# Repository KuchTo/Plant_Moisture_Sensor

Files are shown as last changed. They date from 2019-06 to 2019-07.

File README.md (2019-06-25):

# Plant_Moisture_Sensor
Monitors Plant earth Moisture and some Environment Paramanter like Temperature 

Kurzbeschreibung Projekt:

Mittels des hier vorgestellten Projektes wird der Wassergehalt der Erde überwacht. Dazu besitzt der Pflanzenwächter eine LED-Ampel, die bei feuchter Erde grün leuchtet und bei trockener Erde über gelb rot wird.

Hinweise:

Da die Feuchtigkeit der Erde über eine kapazitive Nahfeldmessung bestimmt wird, ist es notwendig, dass die Feuchtigkeit in unmittelbarer Nähe des Sensors gespeichert wird. Während i.d.R. normale (Blumen-)Pflanzenerde diese Bedingung erfüllt, ist dies bei u.a. bei Hydrokultursubstraten nicht gegeben !

Dieses Projekt ist daher für Hydrokulturpflanzen oder Luftwurzlerpflanzen (wie z.B. Orchideen) nicht geeignet! 

Da Pflanzen ganz unterschiedliche Anforderungen an Ihre Bewässerung habe, liegt die Interpretation der nötigen Aktionen auf die (Ampel-) Anzeige des Projektes ausschließlich in der Hand des Anwenders. 

Der Pflanzenwächter ist daher kein Ersatz für eine verantwortungsvolle- und pflanzengerechte Pflege der Pflanzen.

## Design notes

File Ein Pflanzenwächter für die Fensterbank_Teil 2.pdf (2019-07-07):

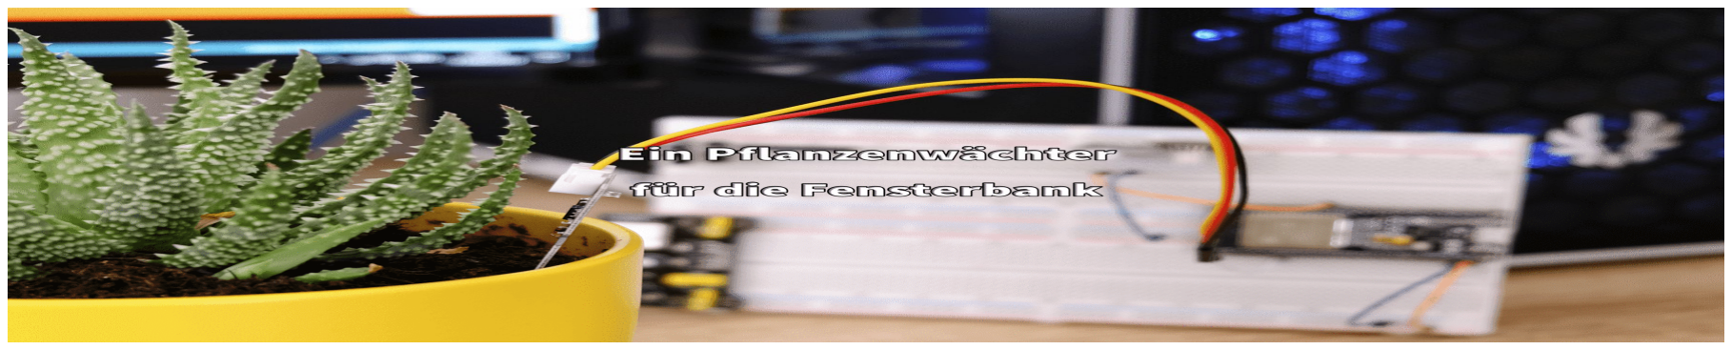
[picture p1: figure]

# Pflanzenwächter für die Fensterbank Teil 2 – Eine eigene Handy App

Hallo und willkommen zum zweiten Teil unserer Pflanzenwächterreihe. Obwohl unser Pflanzenwächter schon ganz gut funktioniert, finde ich es doch als Maker etwas umständlich immer mal wieder nach der Led - „Ampel“ zu schauen, um zu sehen, ob meine Pflanze gegossen werden muss. Viel praktischer fände ich es, wenn ich

jederzeit und überall einfach nur mal kurz auf das Handy schauen muss, um zu wissen,

## wie es der Pflanze zuhause geht. Daher werden wir uns in diesem Teil eine waschechte Handy APP für unseren Wächter bauen!

Doch bevor jetzt jemand jetzt denkt: Das geht doch nicht, das ist doch viel zu kompliziert, schauen wir uns doch mal zuvor genauer im App Store um. Es gibt nämlich eine bereits schon genau für unsere Zwecke konzipierte APP, die wir nur noch hier etwas anpassen müssen, da ein wenig Code zuzufügen müssen und dann das ganze

zusammenfügen! Danach funktioniert unsere APP genauso wie wir es wollen.

## Also los geht’s! Als ersten Schritt laden wir uns die App „Blynk“ aus dem App Store auf unser Handy. Die APP selbst ist kostenlos und kann für unseren, hier im zweiten Teil des Blogs, beschriebenen Anwendungsfall auch ohne weitere zusätzliche Kosten für

die App betrieben werden.

## Für einen späteren weiteren Ausbau der App innerhalb der Blogreihe reichen die „2000

Energie“ Einheiten der kostenlosen Variante jedoch unter Umständen nicht mehr aus.

## Es fallen aber unabhängig von der Ausbaustufe Kosten für die Datenübertragung vom Pflanzenwächter zum Handy an. Bitte berücksichtigt diese Kosten bei dem Nachbau des Projektes!

## Nachdem wir also die App Blynk aus dem Store heruntergeladen haben und diese zum ersten Mal starten, müssen wir uns zuerst einmal einen Account anlegen. Dazu tippen wir auf „Create New Account“

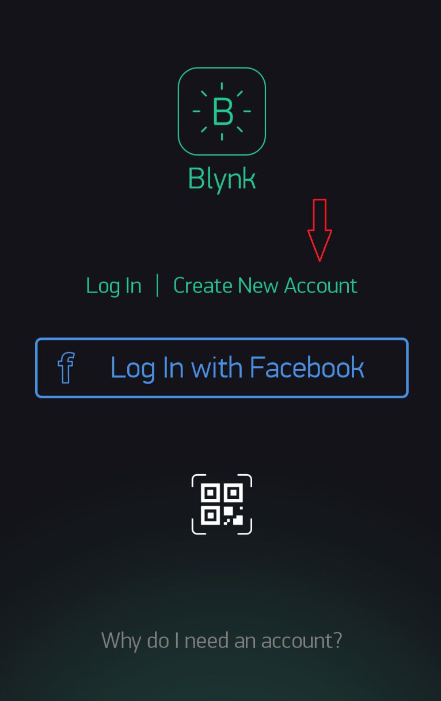
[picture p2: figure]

## Wir registrieren uns mit der eigenen E-Mail-Adresse und vergeben ein Passwort:

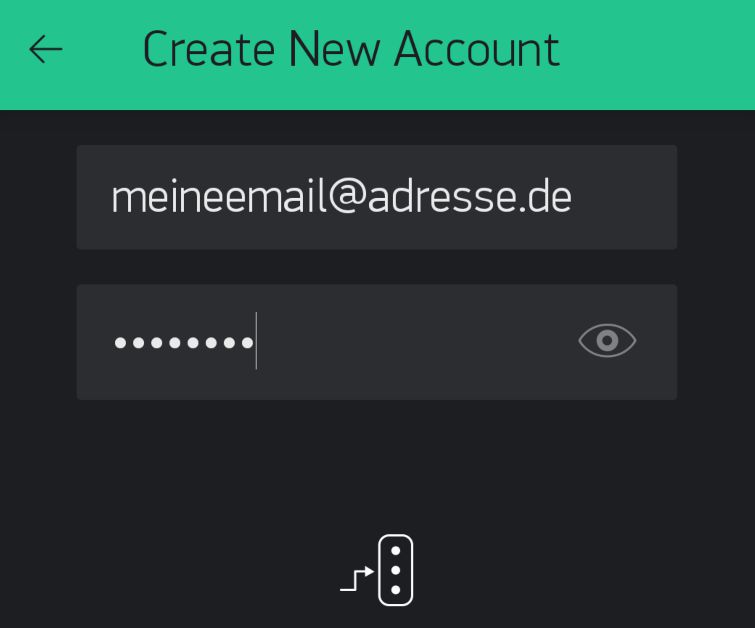
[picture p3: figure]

## Danach klicken wir auf neues Projekt:

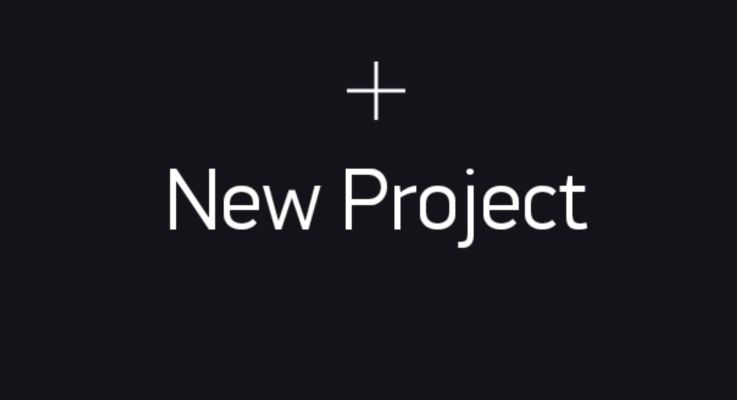
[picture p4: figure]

Wir landen in dem Dialog zur Anlage eines neuen Projektes. Hier müssen die Basisdaten des Projekts ein, wie z.B. den Projektnamen, unsere ESP32 Entwicklungsplattform und die gewünschte Verbindungsform. Es können verschiedene Verbindungsparameter mitgegeben werden, wie Z.B Bluetooth oder auch WLAN. Um jedoch auch Mobil unterwegs Daten empfangen zu können, muss der Verbindungstyp GSM gewählt werden. Nachfolgend sind die Einstellungen, die ich für mein Projekt gewählt habe, gezeigt:

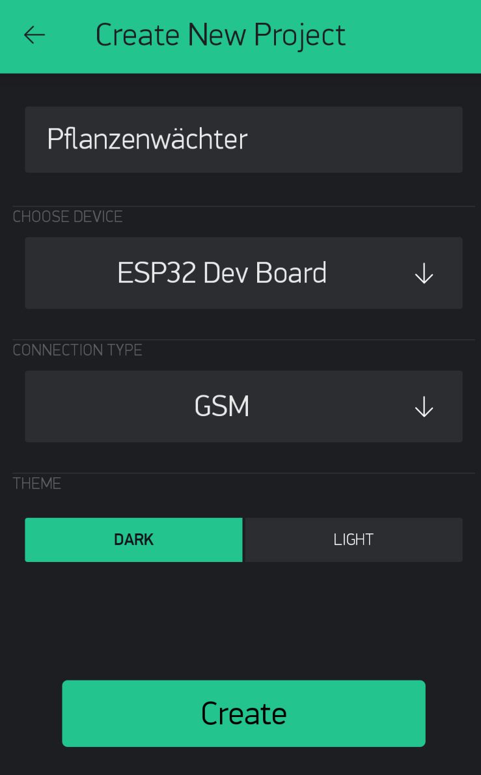
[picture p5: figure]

## Wir bestätigen die Angaben mit „Create“ und landen in einem leeren Projekt. Wir fügen unser erstes Aktives Element in unsere App über das „Plus“ Symbol in der Titelleiste hinzu:

## Wir wählen das Element „Gauge“ aus, und konfigurieren das Element. Zuerst vergeben wir einen NAMEN für das Element. Ich habe mich für den Namen

„Bodenfeuchte Pflanze 1“ entschieden.

## Danach wählen wir als Input Variable „V1“ aus, als Minimalwert 0 und als Maximalwert 100. Das Feld „LABEL“ ergänzen wir mit einem % und stellen als Reading Rate „Push“ ein. Bei dem Design können eine beliebige Farbe und eine beliebige Schriftgröße

gewählt werden.

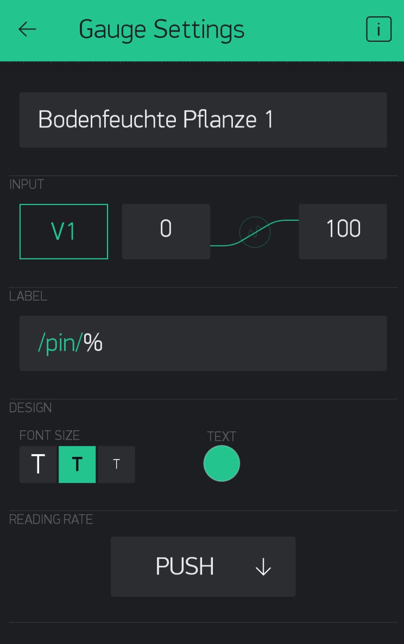
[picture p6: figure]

## Wir bestätigen die Einstellungen mit dem Pfeil links, und landen dann wieder in der Hauptansicht der APP:

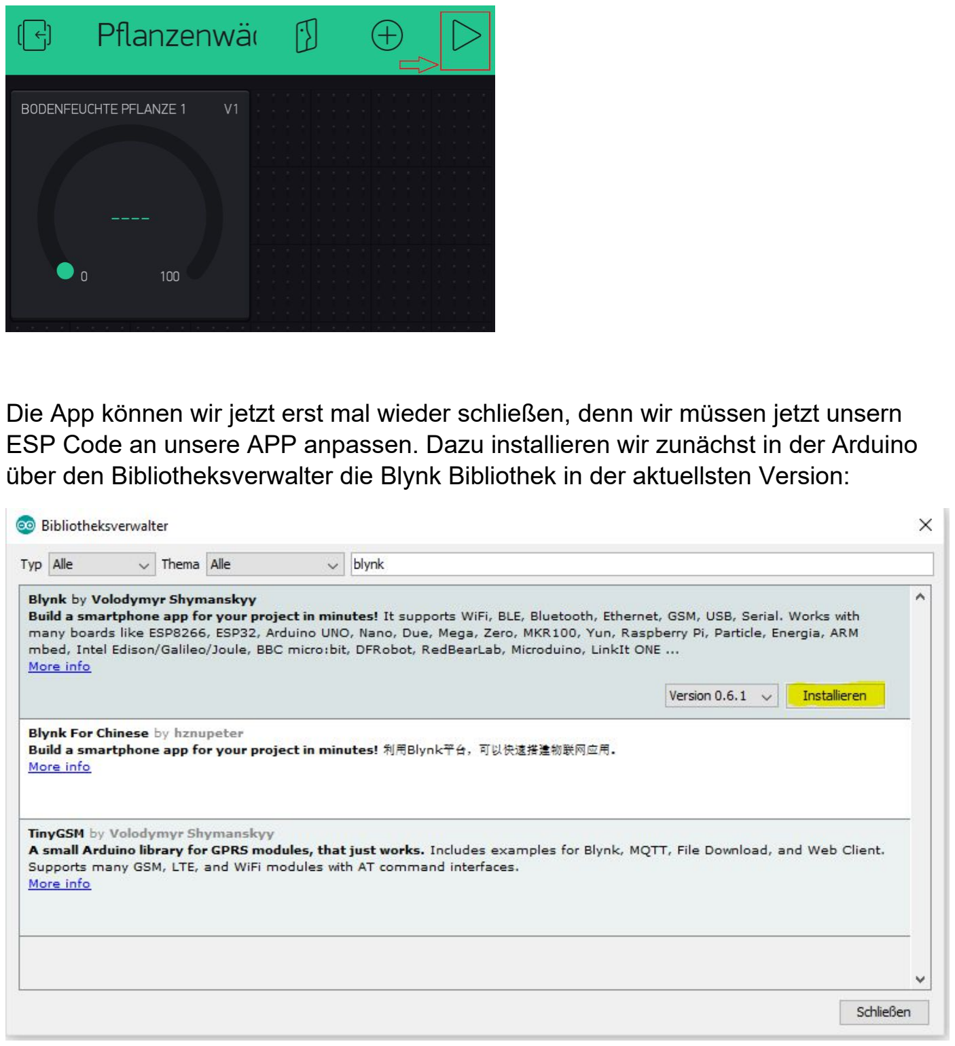
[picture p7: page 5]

## Die App können wir jetzt erst mal wieder schließen, denn wir müssen jetzt unsern ESP Code an unsere APP anpassen. Dazu installieren wir zunächst in der Arduino über den Bibliotheksverwalter die Blynk Bibliothek in der aktuellsten Version:

## Danach fügen wir folgenden Code in die IDE ein:

#include <driver/adc.h>

#include <WiFi.h>

#include <WiFiClient.h>

#include <BlynkSimpleEsp32.h>

// Portedefinierung Led's
#define LED_Rot 18 // Rote LED #define LED_Gelb 14 // Gelbe LED #define LED_Gruen 15 // Gruene LED

// LED PWM Einstellungen
#define PWMfreq 5000 // 5 Khz basisfrequenz #define PWMledChannelA 0

#define PWMledChannelB 1

#define PWMledChannelC 2

#define PWMresolution 8 // 8 Bit Resolution

#define ADCAttenuation ADC_ATTEN_DB_11 //ADC_ATTEN_DB_11 = 0-3,6V Dämpfung ADC

#define MoisureSens_Poll_Interval 60000 // Intervall zwischen zwei Bodenfeuchtemessungen in Millisekunden #define MaxSensors 1

#define BLYNK_PRINT Serial

#define BLYNK_NO_BUILTIN

#define BLYNK_NO_FLOAT

//#define BLYNK_DEBUG

struct MoistureSensorCalibrationData
{
int Data[MaxSensors*2] = {1650,2840}; // Calibration Data für Feuchtigkeitssensor. Bitte Projekt Text beachten und Werte ensprechend anpassen
};

struct MoistureSensorData
{
byte Percent[MaxSensors] = {0}; // Feuchtigkeitssensordaten in Prozent
byte Old_Percent[MaxSensors] = {0}; // Vorherige _ Feuchtigkeitssensordaten in Prozent (Zweck: DatenMenge einsparen.) };

//Global Variables
char auth[] = "xxxxxxxxxxxxxxxxxxxxxxxxxxxxxxxxxxxx"; // Hier lt. Anleitung Auth Token dere Blynk App eintragen (E-Mail).

// Deine WiFi Zugangsdaten.
char ssid[] = "WLANSSID";
char pass[] = "XXXXXXXX"; // Set Password to "" for open networks.

MoistureSensorCalibrationData MCalib;
MoistureSensorData MMeasure;
byte AttachedMoistureSensors; // Detected Active Moisture Sensors (Count)
unsigned long Moisure_ServiceCall_Handler = 0; // Delay Variable for Delay between Moisure Readings

void setup() {
pinMode(LED_Rot,OUTPUT);
pinMode(LED_Gelb,OUTPUT);
pinMode(LED_Gruen,OUTPUT);
Serial.begin(115200); // initialize serial communication at 115200 bits per second: ledcSetup(PWMledChannelA, PWMfreq, PWMresolution);
ledcSetup(PWMledChannelB, PWMfreq, PWMresolution);
ledcSetup(PWMledChannelC, PWMfreq, PWMresolution);
ledcAttachPin(LED_Rot, PWMledChannelA); // attach the channel to the GPIO to be controlled ledcAttachPin(LED_Gelb, PWMledChannelB);
ledcAttachPin(LED_Gruen, PWMledChannelC);
SetLedConfig(255,255,255);
Serial.println(F("Systemkonfiguration:")); AttachedMoistureSensors = DetectMoistureSensors(); Serial.print(AttachedMoistureSensors); Serial.println(F(" Bodenfeuchtigkeitsensor(en)")); Serial.print(F("Verbindung zu WLAN"));

delay(500);
Blynk.begin(auth, ssid, pass); // Initalize WiFi-Connection over Blync Library Serial.println(F(" erfolgreich."));
SetLedConfig(0,0,0);
Run_MoistureSensors(true);
}

byte DetectMoistureSensors () {
#define MinSensorValue 100 byte Detected = 0;

for (int i = 0;i < MaxSensors;i++)
{
int MSensorRawValue = ReadMoistureSensor_Raw_Val(i);
if ( MSensorRawValue > MinSensorValue) { Detected++; } else {break;} }
if (Detected < 1)
{
Serial.println(F("Keine Bodenfeuchtigkeitssesoren erkannt. System angehalten.")); esp_deep_sleep_start();
while(1) {}
}
return Detected;
}

bool SetLedConfig(byte Red,byte yellow,byte green) {
ledcWrite(PWMledChannelA, Red); // Rote LED ledcWrite(PWMledChannelB, yellow); // Gelbe LED ledcWrite(PWMledChannelC, green); // Gruene LED return true;
}

int ReadMoistureSensor_Raw_Val(byte Sensor)
{
int ReturnValue,i;
long sum = 0;
#define NUM_READS 6

adc1_config_width(ADC_WIDTH_BIT_12); //Range 0-4095 switch (Sensor)
{
case 0:
{
adc1_config_channel_atten(ADC1_CHANNEL_0,ADCAttenuation); for (i = 0; i < NUM_READS; i++){ // Averaging algorithm
sum += adc1_get_raw( ADC1_CHANNEL_0 ); //Read analog
}
ReturnValue = sum / NUM_READS;
break;
}
}

return ReturnValue;
}

bool Get_Moisture_DatainPercent()
{
bool ReadisValid = true;
for (int i = 0;i < AttachedMoistureSensors;i++)
{
if ((MCalib.Data[i] == 0) || (MCalib.Data[i+1] == 0)) // MinADC Value maxADC ADC Value {
ReadisValid = false;
return ReadisValid;
}
int RawMoistureValue= ReadMoistureSensor_Raw_Val(i); RawMoistureValue= MCalib.Data[i+1] - RawMoistureValue; RawMoistureValue=MCalib.Data[i] + RawMoistureValue; //Serial.println(MCalib.Data[i]);
//Serial.println(MCalib.Data[i+1]);
//Serial.println(RawMoistureValue);
MMeasure.Percent[i] = map(RawMoistureValue,MCalib.Data[i],MCalib.Data[i+1], 0, 100); if (MMeasure.Percent[i] > 100 ) { ReadisValid = false; }

}
return ReadisValid;
}

void Run_MoistureSensors (bool Init) // HauptFunktion zum Betrieb der Bodenfeuchtesensoren {
byte MinSensValue = 100;
if ((millis() - Moisure_ServiceCall_Handler >= MoisureSens_Poll_Interval) | (Init))
{
Moisure_ServiceCall_Handler = millis();
if (Get_Moisture_DatainPercent()) // Gültige aktuelle Daten Empfangen
{
for (int i = 0;i < AttachedMoistureSensors;i++)
{
if (MMeasure.Percent[i] != MMeasure.Old_Percent[i])
{
MMeasure.Old_Percent[i] = MMeasure.Percent[i];
if (MMeasure.Percent[i] < MinSensValue ) { MinSensValue = MMeasure.Percent[i]; }; Serial.print(F("Feuchtigkeitswert Sensor 1 in Prozent :")); Serial.print(MMeasure.Percent[0]);
Serial.println(F(" %"));
if (i == 0) {Blynk.virtualWrite(V1,MMeasure.Percent[i]); } // Aktualisiere Handywerte }
}
if (MMeasure.Percent[0] > 50)
{ SetLedConfig(0,0,20); }
else if (MMeasure.Percent[0] > 10) {
SetLedConfig(0,255,0);
}
else
{ SetLedConfig(255,0,0); }
}
else // Keine gültigen Daten empfangen
{
Serial.print(F("Bodenfeuchtigkeitssensor nicht kalibiert.Bitte kalibieren. RohDaten des Sensors 1:")); Serial.println(ReadMoistureSensor_Raw_Val(0));
SetLedConfig(255,255,255);
}
}
}

// Main Loop
void loop()
{
Run_MoistureSensors(false);
Blynk.run(); // Execute Blync Basic- Functions }

## Jetzt müssen wir noch unseren Code ein wenig anpassen. Zum einem muss im Code die WLAN Credentials (SSID und Passwort) an das heimische WLAN angepasst werden:

// Deine WiFi Zugangsdaten.
char ssid[] = "WLANSSID";
char pass[] = "XXXXXXXX"; // Set Password to "" for open networks.

## zum anderen haben wir bei der Anlage unseres Projektes in der AP ein Authenticator Token zugesendet bekommen:

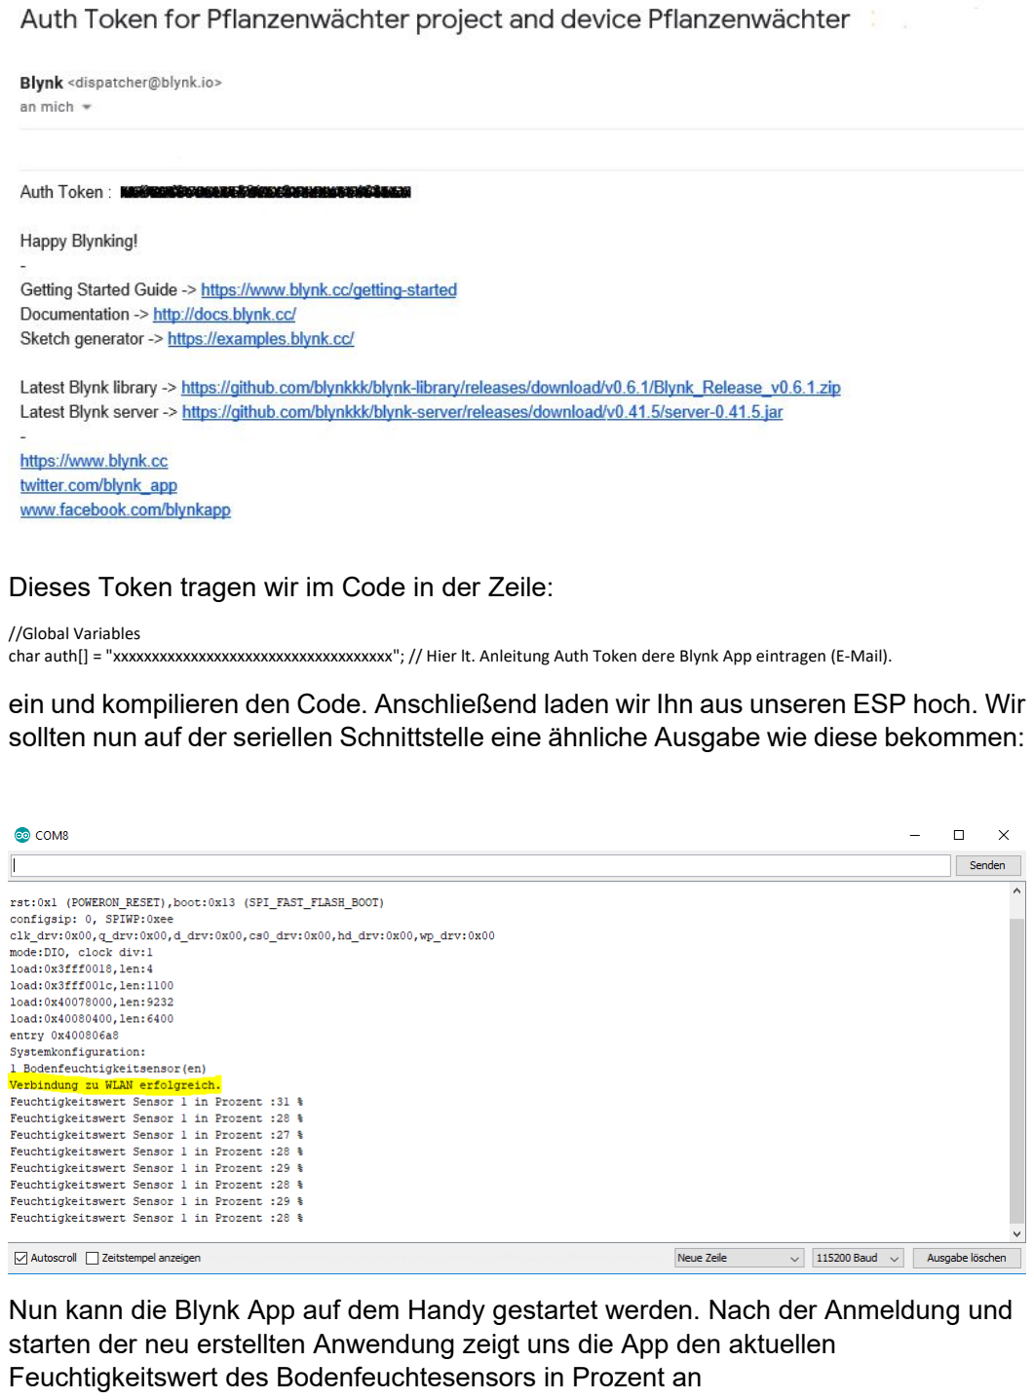
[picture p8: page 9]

## Dieses Token tragen wir im Code in der Zeile:

//Global Variables
char auth[] = "xxxxxxxxxxxxxxxxxxxxxxxxxxxxxxxxxxxx"; // Hier lt. Anleitung Auth Token dere Blynk App eintragen (E-Mail).

## ein und kompilieren den Code. Anschließend laden wir Ihn aus unseren ESP hoch. Wir sollten nun auf der seriellen Schnittstelle eine ähnliche Ausgabe wie diese bekommen:

## Nun kann die Blynk App auf dem Handy gestartet werden. Nach der Anmeldung und starten der neu erstellten Anwendung zeigt uns die App den aktuellen Feuchtigkeitswert des Bodenfeuchtesensors in Prozent an

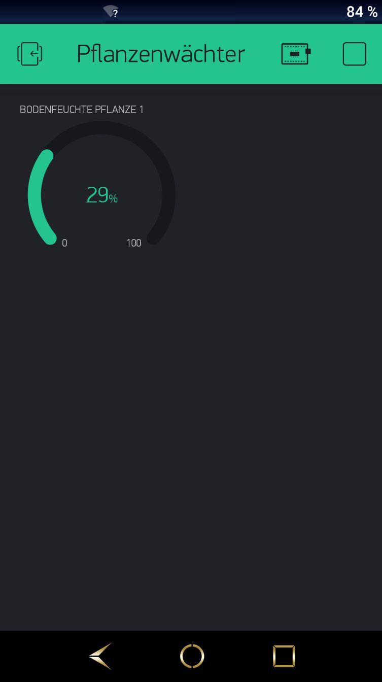
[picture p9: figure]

## Weitere Informationen über die Blynk APP und deren Verwendung in Controllern findest du unter

- Blynk Einführung -> https://www.blynk.cc/getting-started - Dokumentation -> http://docs.blynk.cc/ - Sketch Generator -> https://examples.blynk.cc/ - Aktuellste Blynk Bibliothek -> https://github.com/blynkkk/blynk-library/releases/download/v0.6.1/Blynk_Release_v0.6.1.zip - Aktuellster Blynk server -> https://github.com/blynkkk/blynk-server/releases/download/v0.41.5/server-0.41.5.jar - Blynk Startseite -> https://www.blynk.cc

Ich wünsche viel Spaß beim Nachbauen, und bis zum nächsten Mal.

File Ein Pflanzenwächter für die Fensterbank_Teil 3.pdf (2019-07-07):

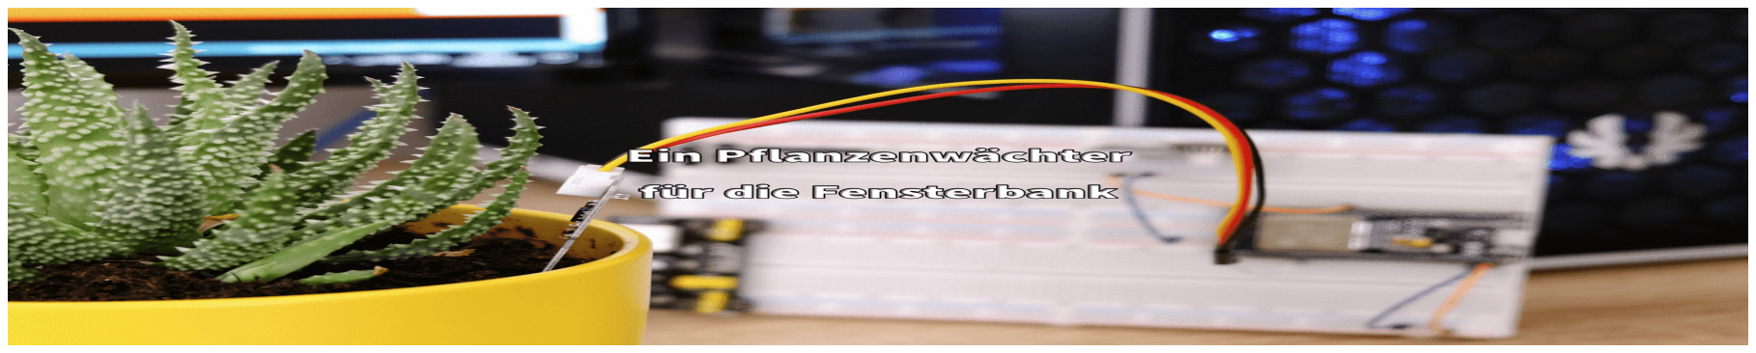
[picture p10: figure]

# Pflanzenwächter für die Fensterbank Teil 3 – Erweiterung der

Bodenfeuchtesensoren auf maximal sechs Stück.

In dem dritten Teil der Reihe „Pflanzenwächter“ kommen wir auf ein, in den vorherigen Teilen bereits implementiertes schaltungstechnisches Detail zurück und erweitern, die Anzahl der an unseren Pflanzenwächter anschließbaren Feuchtesensoren auf maximal sechs. Dem einen oder anderen sind vielleicht die bereits vorhandenen sechs Spannungsteiler aufgefallen, wobei bisher jedoch nur einer davon beschaltet war. Die restlichen 5 Spannungsteiler dienten bisher in der Hauptsache dazu, 5 von 6 Analog-

Digital Eingänge des ESP32 definiert auf 0 zu ziehen um sie einerseits an einem evtl.

unkontrolliertem Schwingen zu hindern, aber auch damit für unseren ESP feststellbar zu machen, an welchen der 6 Eingänge nun ein Feuchtesensor angeschlossen ist und an welchem nicht. Denn es soll, OHNE Änderung des Codes durch einfaches Anschließen eines weiteren Sensors (bis maximal 6) und einem anschließenden Resett des Systems möglich sein, weitere Sensoren nach Belieben und Notwendigkeit anzubinden. Wir können also eine beliebige Anzahl von mindestens 1 bis maximal 6 Sensoren, beginnend mit dem linken Port (GPIO36) folgend bis maximal zu dem rechten Port (GPIO 33) bestücken. Dabei dürfen jedoch keine Ports zwischen

Sensoren ausgelassen werden, da diese andernfalls nicht erkannt werden.

## Nachfolgend ist die Maximalbestückung mit Feuchtesensoren gezeigt:

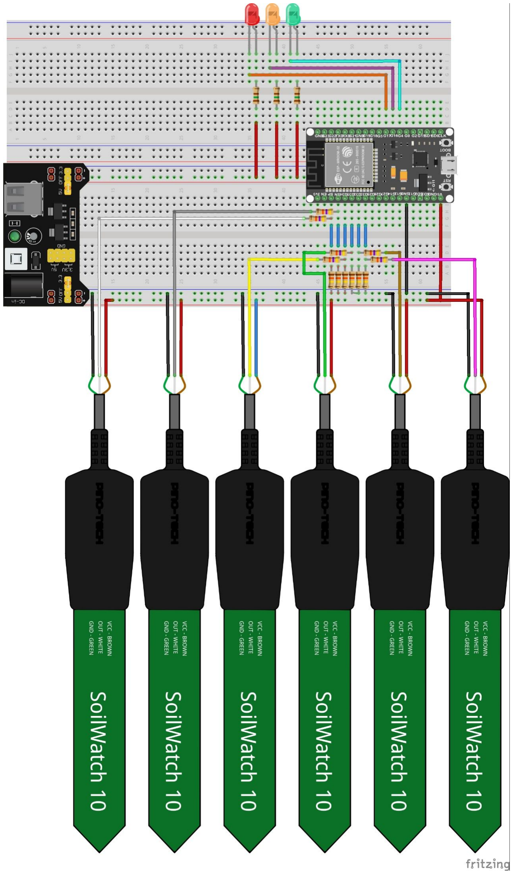
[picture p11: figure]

## Unsere Teileliste erweitert sich somit auf:

## - 1 x LED Farbe Grün (560nm); 5 mm - 1x LED Farbe Gelb (605nm); 5 mm - 1x LED Farbe Rot (633nm); 5 mm

- 6x130kΩ Wiederstand Toleranz ±1%;

## - 6x 47kΩ Wiederstand Toleranz ±1

- 3x 150Ω Wiederstand Toleranz ±1%;

## - 6x Kapazitiver Feuchtesensor

- 1x ESP32-38Pin Variante Generic; Typ NodeMCU-32S; Beinchen 38;

## - 1x YwRobot Breadboard Spannungsversorgung

## Nachdem wir nun die nötigen Hardwareänderungen durchgeführt haben, müssen wir noch unseren Code auf dem ESP ein wenig anpassen sowie unsere Handy-APP erweitern. Zuerst laden wir folgenden Code auf unseren ESP hoch:

#include <driver/adc.h>

#include <WiFi.h>

#include <WiFiClient.h>

#include <BlynkSimpleEsp32.h>

// Portedefinierung Led's
#define LED_Rot 18 // Rote LED #define LED_Gelb 14 // Gelbe LED

#define LED_Gruen 15 // Gruene LED

// LED PWM Einstellungen
#define PWMfreq 5000 // 5 Khz basisfrequenz für LED Anzeige #define PWMledChannelA 0

#define PWMledChannelB 1

#define PWMledChannelC 2

#define PWMresolution 8 // 8 Bit Resolution für LED PWM

//Sonstige Definitionen
#define ADCAttenuation ADC_ATTEN_DB_11 //ADC_ATTEN_DB_11 = 0-3,6V Dämpfung ADC (ADC Erweiterung #define MoisureSens_Poll_Interval 300000 // Intervall zwischen zwei Bodenfeuchtemessungen in Millisekunden -> alle 5 Minuten Datenpaket an Handy senden

#define MaxSensors 6 | // Maximale Anzahl an anschließbaren FeuchteSensoren

#define StartInit true

#define Sens_Calib true

#define Sens_NOTCalib false

// Blynk APP Definitionen
#define BLYNK_GREEN | "#23C48E"

#define BLYNK_BLUE | "#04C0F8"

#define BLYNK_YELLOW "#ED9D00"

#define BLYNK_RED | "#D3435C"

#define BLYNK_BLACK | "#000000"

#define BLYNK_PRINT Serial #define BLYNK_NO_BUILTIN

#define BLYNK_NO_FLOAT

//#define BLYNK_DEBUG

struct MoistureSensorCalibrationData
{
int Data[MaxSensors*2] = {0,0,0,0,0,0,0,0,0,0,0,0,}; // Calibration Data für Feuchtigkeitssensor. Bitte Projekt Text beachten und Werte ensprechend anpassen
String SensorName[MaxSensors] = {"Pflanze 1","Pflanze 2","Pflanze 3","Pflanze 4","Pflanze 5","Pflanze 6"}; // Sensorname, der auch in der APP als Überschrift angezeigt wird
byte StatusBorderPercentValues[MaxSensors*2][2]= { {10,50}, // Zweidimensinonales Array für Prozentgrenzwerte (Ampel) jeweils Einzeln pro Feuchtesensor (1 -6)
{10,50},
{10,50},

{10,50},
{10,50},
{10,50}};
};

struct MoistureSensorData
{
int Percent[MaxSensors] = {0,0,0,0,0,0}; // Feuchtigkeitssensordaten in Prozent
byte Old_Percent[MaxSensors] = {0,0,0,0,0,0}; // Vorherige _ Feuchtigkeitssensordaten in Prozent (Zweck: DatenMenge einsparen.)
bool DataValid [MaxSensors] = {false,false,false,false,false,false};
};

//Global Variables

char auth[] = "xxxxxxxxxxxxxxxxxxxxxxxxxxxxxxxx"; // Hier lt. Anleitung Auth Token dere Blynk App eintragen (E-Mail). // Deine WiFi Zugangsdaten.
char ssid[] = "Deine_WLAN_SSID"; | // Bitte an eigene WLAN SSID anpassen
char pass[] = "Dein _WLAN _Passwort!"; | // Bitte an eigene WLAN Passwort anpassen

MoistureSensorCalibrationData MCalib;
MoistureSensorData MMeasure;
byte AttachedMoistureSensors; // Detected Active Moisture Sensors (Count)
unsigned long Moisure_ServiceCall_Handler = 0; // Delay Variable for Delay between Moisure Readings

void setup() {
pinMode(LED_Rot,OUTPUT);
pinMode(LED_Gelb,OUTPUT);
pinMode(LED_Gruen,OUTPUT);
Serial.begin(115200); // initialize serial communication at 115200 bits per second: ledcSetup(PWMledChannelA, PWMfreq, PWMresolution);
ledcSetup(PWMledChannelB, PWMfreq, PWMresolution);
ledcSetup(PWMledChannelC, PWMfreq, PWMresolution);
ledcAttachPin(LED_Rot, PWMledChannelA); // attach the channel to the GPIO to be controlled ledcAttachPin(LED_Gelb, PWMledChannelB);
ledcAttachPin(LED_Gruen, PWMledChannelC);
SetLedConfig(255,255,255);
Serial.println(F("Systemkonfiguration:")); AttachedMoistureSensors = DetectMoistureSensors(); Serial.print(AttachedMoistureSensors); Serial.println(F(" Bodenfeuchtigkeitsensor(en)"));
Serial.print(F("Verbindung zu WLAN"));
delay(500);
Blynk.begin(auth, ssid, pass); // Initalize WiFi-Connection over Blync Library Serial.println(F(" erfolgreich."));
SetLedConfig(0,0,0);
Init_Blynk_APP();
Run_MoistureSensors(StartInit);
for (int i = AttachedMoistureSensors;i < 6;i++) { Update_Blynk_APP(i,Sens_Calib); }; }

byte DetectMoistureSensors ()
{
#define MinSensorValue 100 byte Detected = 0;

for (int i = 0;i < MaxSensors;i++)
{
int MSensorRawValue = ReadMoistureSensor_Raw_Val(i);
if ( MSensorRawValue > MinSensorValue) { Detected++; } else {break;} }
if (Detected < 1)
{
Serial.println(F("Keine Bodenfeuchtigkeitssesoren erkannt. System angehalten.")); esp_deep_sleep_start();
while(1) {}
}
return Detected;
}

bool SetLedConfig(byte Red,byte yellow,byte green) {
ledcWrite(PWMledChannelA, Red); // Rote LED ledcWrite(PWMledChannelB, yellow); // Gelbe LED ledcWrite(PWMledChannelC, green); // Gruene LED return true;
}

int ReadMoistureSensor_Raw_Val(byte Sensor) {
int ReturnValue,i;
long sum = 0;
#define NUM_READS 6

adc1_config_width(ADC_WIDTH_BIT_12); //Range 0-4095 switch (Sensor)
{
case 0:
{
adc1_config_channel_atten(ADC1_CHANNEL_0,ADCAttenuation); for (i = 0; i < NUM_READS; i++){ // Averaging algorithm
sum += adc1_get_raw( ADC1_CHANNEL_0 ); //Read analog
}
ReturnValue = sum / NUM_READS;
break;
}
case 1:
{
adc1_config_channel_atten(ADC1_CHANNEL_3,ADCAttenuation); for (i = 0; i < NUM_READS; i++){ // Averaging algorithm
sum += adc1_get_raw( ADC1_CHANNEL_3 ); //Read analog
}
ReturnValue = sum / NUM_READS;
break;
}
case 2:
{
adc1_config_channel_atten(ADC1_CHANNEL_6,ADCAttenuation); for (i = 0; i < NUM_READS; i++){ // Averaging algorithm
sum += adc1_get_raw( ADC1_CHANNEL_6 ); //Read analog
}
ReturnValue = sum / NUM_READS;
break;
}
case 3:
{
adc1_config_channel_atten(ADC1_CHANNEL_7,ADCAttenuation); for (i = 0; i < NUM_READS; i++){ // Averaging algorithm
sum += adc1_get_raw( ADC1_CHANNEL_7 ); //Read analog
}
ReturnValue = sum / NUM_READS;
break;
}
case 4:
{
adc1_config_channel_atten(ADC1_CHANNEL_4,ADCAttenuation); for (i = 0; i < NUM_READS; i++){ // Averaging algorithm
sum += adc1_get_raw( ADC1_CHANNEL_4 ); //Read analog
}
ReturnValue = sum / NUM_READS;
break;
}
default:
{
adc1_config_channel_atten(ADC1_CHANNEL_5,ADCAttenuation); for (i = 0; i < NUM_READS; i++){ // Averaging algorithm
sum += adc1_get_raw( ADC1_CHANNEL_5 ); //Read analog
}
ReturnValue = sum / NUM_READS;
break;
}
}

return ReturnValue;
}

void Init_Blynk_APP()
{
Blynk.setProperty(V1,"label",MCalib.SensorName[0]); Blynk.setProperty(V2,"label",MCalib.SensorName[1]); Blynk.setProperty(V3,"label",MCalib.SensorName[2]); Blynk.setProperty(V4,"label",MCalib.SensorName[3]); Blynk.setProperty(V5,"label",MCalib.SensorName[4]); Blynk.setProperty(V6,"label",MCalib.SensorName[5]); }

void Update_Local_Display() {
byte red1 = 0;
byte yellow1 = 0;
byte green1 = 0;
for (byte i = 0;i < AttachedMoistureSensors;i++) {
if (MMeasure.DataValid[i])
{
if ( MMeasure.Percent[i] > MCalib.StatusBorderPercentValues[i][1])
{
green1++;
} else if ( MMeasure.Percent[i] > MCalib.StatusBorderPercentValues[i][0]) {
yellow1++;
} else
{
red1++;
}
}
}
if (red1 > 0)
{ SetLedConfig(255,0,0); } else if (yellow1 > 0)
{ SetLedConfig(0,255,0); } else if (green1 > 0)
{ SetLedConfig(0,0,100); } else
{ SetLedConfig(100,100,100); }
}

void Update_Blynk_APP(byte Sensor,bool Calibrated) {
switch (Sensor)
{
case 0:
{
if ((MMeasure.DataValid[0]) & (Calibrated))
{
if ( MMeasure.Percent[0] > MCalib.StatusBorderPercentValues[0][1])
{
Blynk.setProperty(V1,"color",BLYNK_GREEN);
} else if ( MMeasure.Percent[0] > MCalib.StatusBorderPercentValues[0][0]) {
Blynk.setProperty(V1,"color",BLYNK_YELLOW);
} else
{
Blynk.setProperty(V1,"color",BLYNK_RED);
}
delay(100);
Blynk.virtualWrite(V1,MMeasure.Percent[0]); } else
{
if (Calibrated)
{
Blynk.setProperty(V1,"label","Deaktiviert"); delay(100);
Blynk.virtualWrite(V1,0);
delay(100);
Blynk.setProperty(V1,"color",BLYNK_BLACK); }
else
{
Blynk.virtualWrite(V1,0);
delay(100);
Blynk.setProperty(V1,"color",BLYNK_BLUE); }
}
break;
}
case 1:
{
if ((MMeasure.DataValid[1]) & (Calibrated))
{
if ( MMeasure.Percent[1] > MCalib.StatusBorderPercentValues[1][1]) {

Blynk.setProperty(V2,"color",BLYNK_GREEN);
} else if ( MMeasure.Percent[1] > MCalib.StatusBorderPercentValues[1][0]) {
Blynk.setProperty(V2,"color",BLYNK_YELLOW);
} else
{
Blynk.setProperty(V2,"color",BLYNK_RED);
}
delay(100);
Blynk.virtualWrite(V2,MMeasure.Percent[1]); } else
{
if (Calibrated)
{
Blynk.setProperty(V2,"label","Deaktiviert"); delay(100);
Blynk.virtualWrite(V2,0);
delay(100);
Blynk.setProperty(V2,"color",BLYNK_BLACK); }
else
{
Blynk.virtualWrite(V2,0);
delay(100);
Blynk.setProperty(V3,"color",BLYNK_BLUE); }
}
break;
}
case 2:
{
if ((MMeasure.DataValid[2]) & (Calibrated))
{
if ( MMeasure.Percent[2] > MCalib.StatusBorderPercentValues[2][1])
{
Blynk.setProperty(V3,"color",BLYNK_GREEN);
} else if ( MMeasure.Percent[2] > MCalib.StatusBorderPercentValues[2][0]) {
Blynk.setProperty(V3,"color",BLYNK_YELLOW);
} else
{
Blynk.setProperty(V3,"color",BLYNK_RED);
}
delay(100);
Blynk.virtualWrite(V3,MMeasure.Percent[2]); } else
{
if (Calibrated)
{
Blynk.setProperty(V3,"label","Deaktiviert"); delay(100);
Blynk.virtualWrite(V3,0);
delay(100);
Blynk.setProperty(V3,"color",BLYNK_BLACK); }
else
{
Blynk.virtualWrite(V3,0);
delay(100);
Blynk.setProperty(V3,"color",BLYNK_BLUE); }
}
break;
}
case 3:
{
if ((MMeasure.DataValid[3]) & (Calibrated))
{
if ( MMeasure.Percent[3] > MCalib.StatusBorderPercentValues[3][1])
{
Blynk.setProperty(V4,"color",BLYNK_GREEN);
} else if ( MMeasure.Percent[3] > MCalib.StatusBorderPercentValues[3][0]) {
Blynk.setProperty(V4,"color",BLYNK_YELLOW);
} else
{
Blynk.setProperty(V4,"color",BLYNK_RED);

}
delay(100);
Blynk.virtualWrite(V4,MMeasure.Percent[3]); } else
{
if (Calibrated)
{
Blynk.setProperty(V4,"label","Deaktiviert"); delay(100);
Blynk.virtualWrite(V4,0);
delay(100);
Blynk.setProperty(V4,"color",BLYNK_BLACK); }
else
{
Blynk.virtualWrite(V4,0);
delay(100);
Blynk.setProperty(V4,"color",BLYNK_BLUE); }
}
break;
}
case 4:
{
if ((MMeasure.DataValid[4]) & (Calibrated))
{
if ( MMeasure.Percent[4] > MCalib.StatusBorderPercentValues[4][1])
{
Blynk.setProperty(V5,"color",BLYNK_GREEN);
} else if ( MMeasure.Percent[4] > MCalib.StatusBorderPercentValues[4][0]) {
Blynk.setProperty(V5,"color",BLYNK_YELLOW);
} else
{
Blynk.setProperty(V5,"color",BLYNK_RED);
}
delay(100);
Blynk.virtualWrite(V5,MMeasure.Percent[4]); } else
{
if (Calibrated)
{
Blynk.setProperty(V5,"label","Deaktiviert"); delay(100);
Blynk.virtualWrite(V5,0);
delay(100);
Blynk.setProperty(V5,"color",BLYNK_BLACK); }
else
{
Blynk.virtualWrite(V5,0);
delay(100);
Blynk.setProperty(V5,"color",BLYNK_BLUE); }
}
break;
}
default:
{
if ((MMeasure.DataValid[5]) & (Calibrated))
{
if ( MMeasure.Percent[5] > MCalib.StatusBorderPercentValues[5][1])
{
Blynk.setProperty(V6,"color",BLYNK_GREEN);
} else if ( MMeasure.Percent[5] > MCalib.StatusBorderPercentValues[5][0]) {
Blynk.setProperty(V6,"color",BLYNK_YELLOW);
} else
{
Blynk.setProperty(V6,"color",BLYNK_RED);
}
delay(100);
Blynk.virtualWrite(V6,MMeasure.Percent[5]); } else
{
if (Calibrated)
{

Blynk.setProperty(V6,"label","Deaktiviert"); delay(100);
Blynk.virtualWrite(V6,0);
delay(100);
Blynk.setProperty(V6,"color",BLYNK_BLACK); }
else
{
Blynk.virtualWrite(V6,0);
delay(100);
Blynk.setProperty(V6,"color",BLYNK_BLUE); }
}
break;
}
} // End Switch
}

void Get_Moisture_DatainPercent()
{
byte CalibDataOffset = 0;
for (byte i = 0;i < AttachedMoistureSensors;i++)
{
CalibDataOffset = i *2;
int RawMoistureValue = ReadMoistureSensor_Raw_Val(i);
if ((MCalib.Data[CalibDataOffset] == 0) || (MCalib.Data[CalibDataOffset+1] == 0)) // MinADC Value maxADC ADC Value {
MMeasure.Percent[i] = RawMoistureValue;
MMeasure.DataValid[i] = false;
} else
{
RawMoistureValue= MCalib.Data[CalibDataOffset+1] - RawMoistureValue; RawMoistureValue=MCalib.Data[CalibDataOffset] + RawMoistureValue;
MMeasure.Percent[i] = map(RawMoistureValue,MCalib.Data[CalibDataOffset],MCalib.Data[CalibDataOffset+1], 0, 100);
if ((MMeasure.Percent[i] > 100 ) | (MMeasure.Percent[i] < 0 ))
{
MMeasure.Percent[i] = RawMoistureValue;
MMeasure.DataValid[i] = false;
} else { MMeasure.DataValid[i] = true; } }
}
return ;
}

void Run_MoistureSensors (bool Init) // HauptFunktion zum Betrieb der Bodenfeuchtesensoren {
byte MinSensValue = 100;
if ((millis() - Moisure_ServiceCall_Handler >= MoisureSens_Poll_Interval) | (Init))
{
Moisure_ServiceCall_Handler = millis();
Get_Moisture_DatainPercent();
for (int i = 0;i < AttachedMoistureSensors;i++) {
if (MMeasure.DataValid[i])
{

if (MMeasure.Percent[i] != MMeasure.Old_Percent[i])
{

MMeasure.Old_Percent[i] = MMeasure.Percent[i];
if (MMeasure.Percent[i] < MinSensValue ) { MinSensValue = MMeasure.Percent[i]; }; Serial.print(F("Feuchtigkeitswert Sensor "));
Serial.print(i);
Serial.print(F(" in Prozent :"));
Serial.print(MMeasure.Percent[i]);
Serial.println(F(" %"));
Update_Blynk_APP(i,Sens_Calib); // Aktualisiere Handywerte }
} else
{
Update_Blynk_APP(i,Sens_NOTCalib); // Aktualisiere Handywerte Serial.print(F("Sensor "));
Serial.print(i);
Serial.print(F(" nicht kalibiert. Bitte kalibrieren. Rohdatenwert:")); Serial.println(MMeasure.Percent[i]);

}
}
Update_Local_Display(); // Aktualisiere lokales Pflanzenwächter Display (Led) }
}

// Main Loop
void loop()
{
Run_MoistureSensors(false);
Blynk.run(); // Execute Blync Basic- Functions }

## Es ist vor dem hochladen auf unseren ESP zu beachten, das folgende Parameter/Codezeilen an die jeweiligen Bedürfnisse angepasst werden müssen:

int Data[MaxSensors*2] = {0,0,0,0,0,0,0,0,0,0,0,0,};

Werte bitte gemäß Beschreibung in Teil 1 der Reihe anpassen.

## #define MoisureSens_Poll_Interval 300000

## Intervall zwischen zwei Bodenfeuchtemessungen in Millisekunden. Der Wert hat darauf Einfluss, wie oft die Handydaten aktualisiert werden, und damit auch, welches Datenvolumen für die Übertragung pro Zeit anfällt. Je höher, desto größeres

Intervall. Bitte auf einen Wert setzen, der zu dem eigenen Datenvolumen bzw.

## Budget passt. [Beispiel: 300000 ms = 5 Minuten Datenübertragungsintervall}

char auth[] = "xxxxxxxxxxxxxxxxxxxxxxxxxxxxxxxx";
char ssid[] = "Deine_WLAN_SSID";
char pass[] = "Dein _WLAN _Passwort!";

Werte bitte gemäß Beschreibung in Teil 2 der Reihe anpassen.

## Es können folgende Parameter/Codezeilen, an die jeweiligen Bedürfnisse angepasst werden:

String SensorName[MaxSensors] = {"Pflanze 1","Pflanze 2","Pflanze 3","Pflanze 4","Pflanze 5","Pflanze 6"};

Feuchtesensorname, der in der APP als Überschrift angezeigt wird.

byte StatusBorderPercentValues[MaxSensors*2][2]= { {10,50}, …..

Zweidimensionales Array für Prozentgrenzwerte (Ampel) jeweils einzeln pro Feuchtesensor (1 -6). Hat Einfluss auf die „Ampel“ Anzeige und die Anzeige der Werte in der APP. Erster Wer (10) gibt die Übergangsgrenze zwischen Status „rot“ und Status „gelb“ an. Zweiter Wert gibt die Übergangsgrenze zwischen Status „gelb“ und Status „grün“ an. Beispiel: ab 51 % Bodenfeuchte „grün“ ab 9% Bodenfeuchte „rot“

## Wenn alle genannten Parameter korrekt definiert worden sollte die Ausgabe auf dem seriellen Monitor nun wie folgt aussehen:

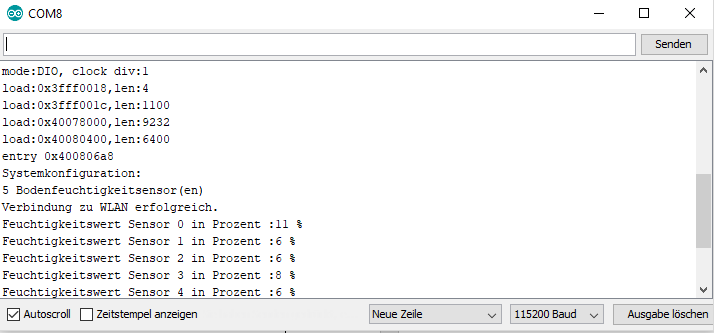
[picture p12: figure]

Hinweis: In diesem Beispiel sind statt max6. nur 5 Sensoren angeschlossen

## Als nächstes müssen wir unsere HandyApp noch auf die veränderte Hardware und

Firmware anpassen.

## Da wir in unserer Blynk HandyAPP nur 2000 Energiepunkte kostenlos zur Verfügung gestellt bekommen, müssen wir bei 6 angebundenen Sensoren etwas haushalten. Im

ersten Schritt löschen wir daher das im zweiten Teil angelegte „Gauge“ Element.

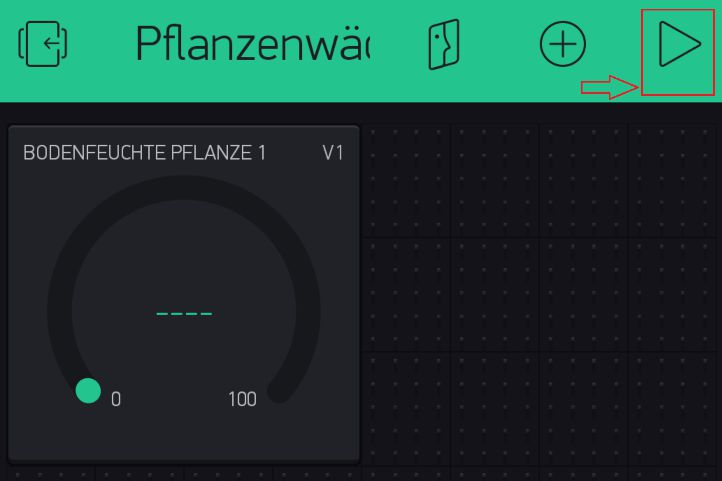
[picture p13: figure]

## Das „Gauge“ Element ersetzen wir durch das “Level H“ Element

## Nun fügen wir also zur Anzeige der aktuellen Bodenfeuchte das Energiegünstigere

Element „Level H“ insgesamt 6-mal hinzu.

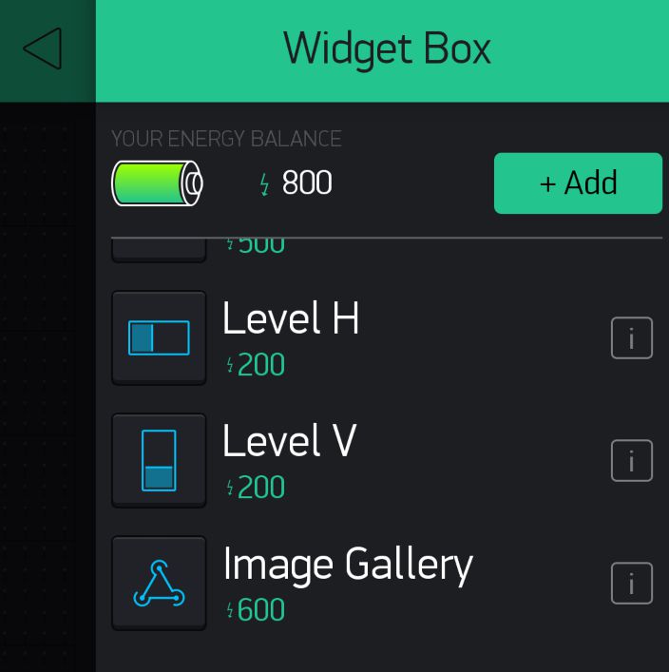
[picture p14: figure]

## Nun sollte unsere Oberfläche ungefähr so aussehen:

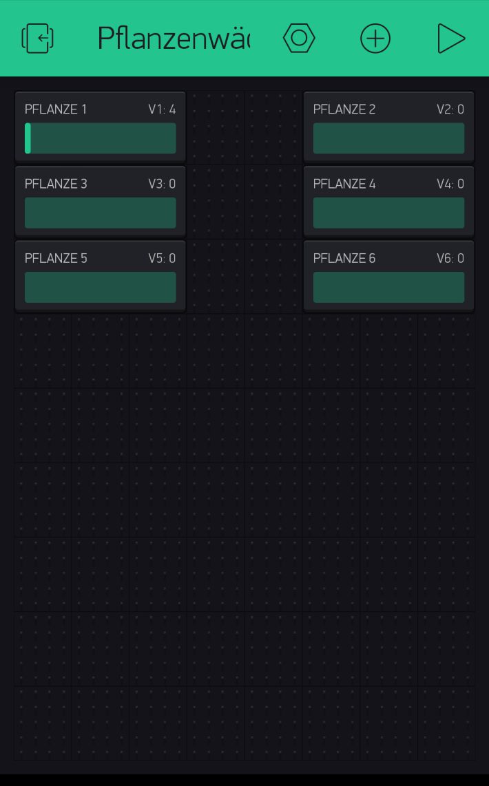
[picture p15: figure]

## Nun müssen wir noch drei Werte jeweilig in den Eigenschaften der 6 Elemente anpassen. Exemplarisch zeige ich hier die Einstellungen für den ersten Sensor

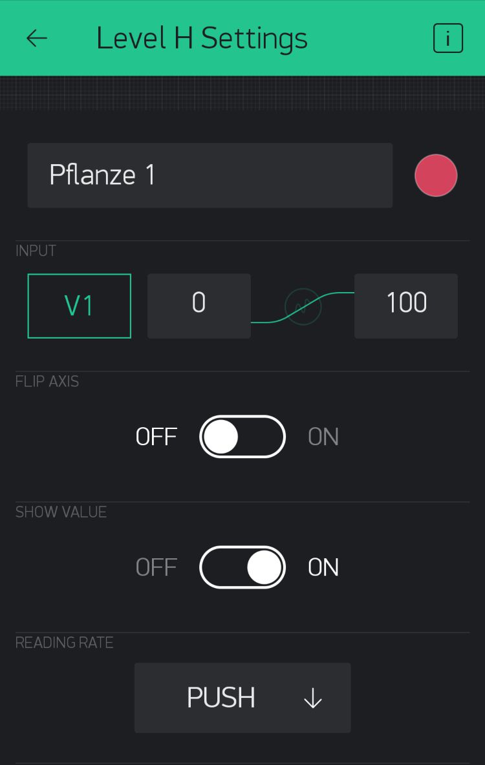
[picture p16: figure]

Die wichtigste Anpassung ist hierbei die Input Variable. Diese muss fortlaufend für jedes „Level H“ Element angefangen von Input „V1“ für Pflanze 1 bis zu „V6“ für Pflanze 6 definiert werden. „V“ steht dabei für „Virtuelle Pins“ und ermöglichen eine Zuordnung zwischen den Elementen der APP und der Anweisungen im Code. Weiterhin wählen wir als Minimalwert 0 und als Maximalwert 100 aus. Als drittes definieren wir als Reading Rate „Push“ ein. Bei dem Design können eine beliebige Farbe, eine beliebige Schriftgröße und ein beliebiger Name gewählt werden, da diese Parameter später

durch unser Programm auf dem ESP gesetzt bzw. definiert werden.

## Das Endergebnis, bei Aktivierung des Projekts sollte nun ungefähr wie folgt aussehen:

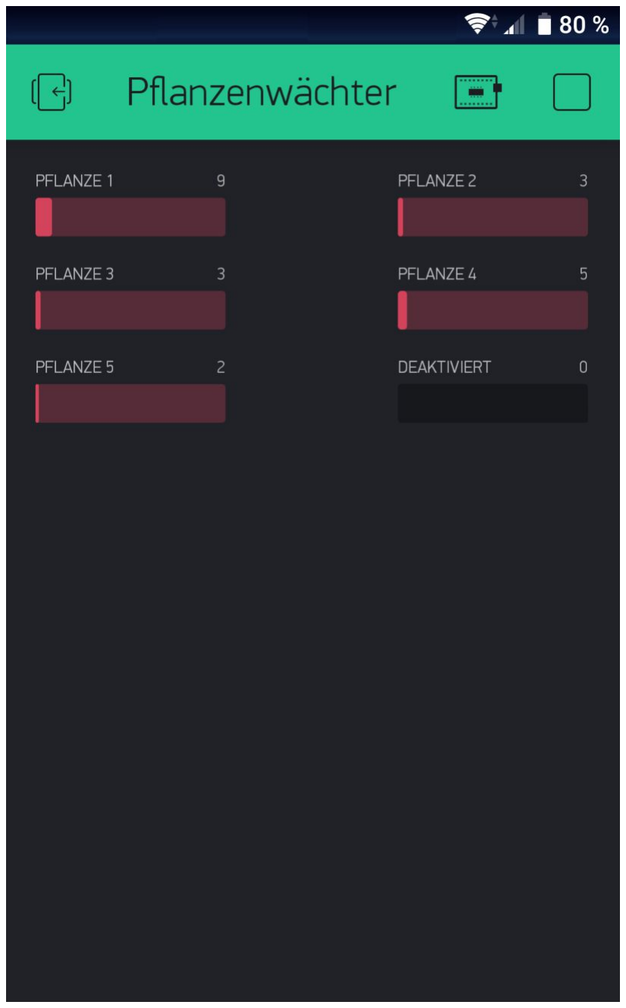
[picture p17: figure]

(der letzte Sensor wird als deaktiviert dargestellt, da ich in dem Beispiel nur 5 Sensoren angeschlossen habe. Bei Verwendung von 6 Sensoren wird das Feld automatisch aktiviert)

## Weitere Informationen über die Blynk APP und deren Verwendung in Controllern findest du unter

- Blynk Einführung -> https://www.blynk.cc/getting-started - Dokumentation -> http://docs.blynk.cc/ - Sketch Generator -> https://examples.blynk.cc/ - Aktuellste Blynk Bibliothek -> https://github.com/blynkkk/blynk-library/releases/download/v0.6.1/Blynk_Release_v0.6.1.zip - Aktuellster Blynk server -> https://github.com/blynkkk/blynk-server/releases/download/v0.41.5/server-0.41.5.jar - Blynk Startseite -> https://www.blynk.cc

Ich wünsche viel Spaß beim Nachbauen, und bis zum nächsten Mal.

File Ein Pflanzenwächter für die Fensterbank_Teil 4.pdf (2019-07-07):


# Pflanzenwächter für die Fensterbank Teil 4 – Temperatur und Luftfeuchtigkeitsmessung

Hallo und Willkommen zu einem weiteren Teil der Pflanzenwächterreihe.

Heute werden wir dem Pflanzenwächter einen 2 in 1 Umweltsensor spendieren, sowie einige Optimierungen der (LED-)Hardware als auch des Codes implementieren. Der Sensor, den wir in diesem Teil anschließen, ist der bekannte DHT 22 Temperatur und Luftfeuchtigkeitssensor. Damit kann unser Pflanzenwächter zukünftig neben der Bodenfeuchte jetzt auch die für Pflanzen in Ihrer Umgebung wichtigen Umwelt-Parameter Temperatur und Luftfeuchtigkeit erfassen. Natürlich werden wir auch unsere Handy APP passend dazu erweitern. Zuallererst nehmen wir eine Änderung der Beschaltung der LED's vor. Wir verwenden dazu das KY-016 LED RGB Modul und schließen dieses direkt wie folgt an:

Rot an Pin 0 , Grün an Pin 15, und Blau an Pin . Vorteile dieses Moduls sind, das wir zum einen bei Einbau in ein Gehäuse Platz sparen ( 1/3 des Gehäuseplatzes) , aber auch per PWM Ansteuerung der einzelnen Kanäle über das volle RGB Spektrum an Farben verfügen, sodass darüber mehr als ursprünglich nur 3 Zustände angezeigt

werden können.
(Beispielsweise leuchtet die LED in der Initialisierungsphase jetzt in weiß). Nicht zuletzt

## sparen wir uns die Vorwiederstände ein, da diese jetzt bereits auf dem Modul integriert sind. Die Pins, an denen die RGB LED's an den ESP32 angeschlossen sind, wurden

nach dem Kriterium "für Timing unkritische Hardware geeignet" ausgewählt. Hintergrund ist, dass die Pins...

## an den die LED anschlossen ist, Firmware bedingt während eines Systemneustarts schwingen (PWM) bevor sie initialisiert werden, und somit für Timing kritische

Hardware (wie den DHT22) nicht geeignet sind.

## Eine Änderung hat sich auch in der Funktionsweise und der Darstellung der LED Anzeige ergeben: Da wir nur eine und nicht sechs RGB LED‘s haben um Statis des Wächters anzuzeigen, müssen wir also die wichtigsten Informationen darauf

zusammenfassen.

Dazu greifen wir auf folgende Überlegung zurück: Für uns ist es die wichtigste Information, ob eine der maximal 6 Pflanzen gegossen werden sollte oder nicht. D.h sollte auf einem Blick dies erkennbar sein. Dazu definieren wir die Farbe grün (Ausreichend Feuchtigkeit) so um, das ALLE 6 Pflanzen genügend Feuchtigkeit haben, damit wir eine „grüne“ Anzeige bekommen. Sollte also einer der sechs

Sensoren weniger als 50% Bodenfeuchte detektiere, springt unsere Anzeige auf „gelb“. Bei unter 10% auf „rot“. Somit wissen wir also das wir unsere Pflanzenwächter APP starten sollten, um zu erfahren, welche der sechs Pflanzen gegossen werden sollte. Da der Temperatur und Feuchtesensor DHT 22 3,3 V Pin und Logikkompatibel ist, schließen wir ihn direkt an den Port 4 des ESP's an. Hier sehr ihr die komplette Beschaltung:

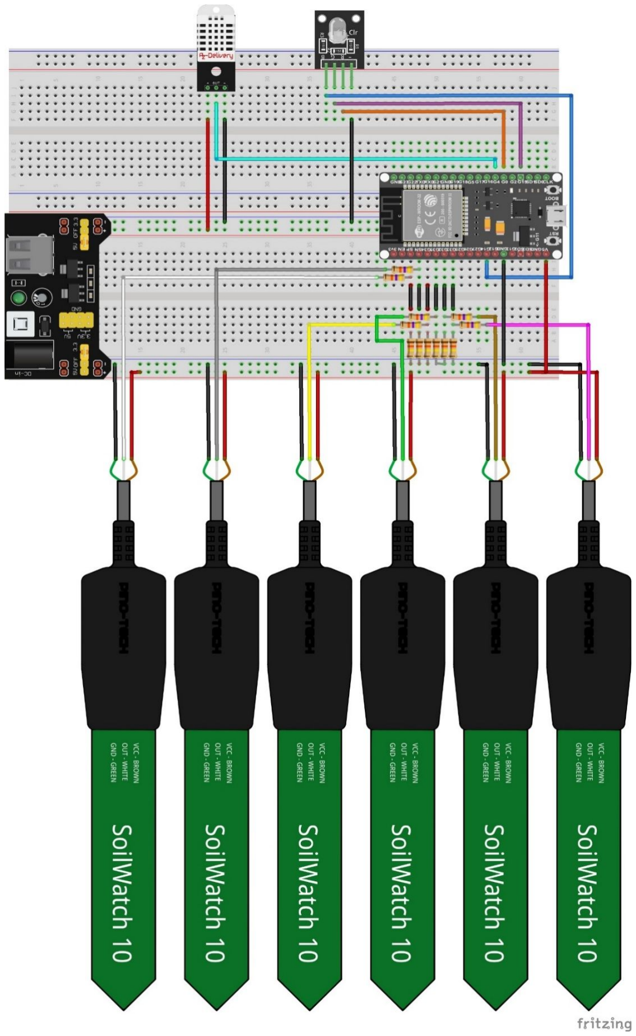
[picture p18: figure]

## Die aktuelle Teileliste mit den benötigten Hardwareteilen. (Mit Bezugslink)

Anzahl | Beschreibung | Anmerkung
1 | DHT 22
| DHT 11 | Alternativ zu DHT 22
1 | KY-016 LED RGB Modul
1 | ESP-32 Dev Kit C
6 | Bodenfeuchte Sensor Modul V1.2
1 | MB102 Netzteil Adapter | Für Breadboardaufbau
12 | Wiederstände laut Beschreibung

## Anstelle des zuerst gelisteten DHT 22 Sensors auch der preisgünstigere DHT 11

Sensor durch einfaches Anpassen der Zeile „DHTTYPE DHT22“verwendet werden. Der DHT 11ist jedoch nicht so Messgenau wie der DHT 22.
Hier finden sich die Unterschiede der beiden Sensoren auch noch mal zum Nachlesen.

## Wenn der DHT 11 Senor verwendet werden soll , muss die Zeile

## #define DHTTYPE DHT22

in

## #define DHTTYPE DHT11

geändert werden. Weitere Änderungen sind nicht notwendig.

## Die Pinbelegung es ESP32 ist wie folgt

ESP32 PIN | Verwendung | Anmerkung
4 | DHT Sensor Eingang
0 | RGB LED PIN | Rot
15 | RGB LED PIN | Grün
14 | RGB LED PIN | Blau

## Dies waren auch schon die notwendigen Hardwareänderungen. Um den DHT22/DHT 11 Sensor mit seinem proprietärem one Wire Protocol in unserem Sketch nutzen zu

können, müssen wir als nächstes zwei weitere Bibliotheken in unsere IDE einbinden.

## Dies ist zum einen die gerneralisierte „Adafruit Unified Sensor Libary“ : als auch die eigentliche DHT Sensor Library. Beide Bibliotheken bauen aufeinander auf und müssen zu unseren Bibliotheken der IDE hinzugefügt werden, da sie von unserem

Projekt benötigt werden.

## Nach Hinzufügen der Bibliotheken und Anpassung der Parameter im Code , wie im Teil 3 dieser Reihe, beschrieben laden wir folgenden Code auf unseren ESP hoch:

#include <driver/adc.h>

#include <WiFi.h>

#include <WiFiClient.h>

#include <BlynkSimpleEsp32.h>

#include "EEPROM.h"

#include <Preferences.h>

#include "DHT.h" // REQUIRES the following Arduino libraries: //- DHT Sensor Library: https://github.com/adafruit/DHT-sensor-library//- Adafruit Unified Sensor Lib: https://github.com/adafruit/Adafruit_Sensor

// Portedefinierung RGP LED Modul
#define LED_Rot | 0 | // Rote LED

#define LED_Blau 14 // Blaue LED

#define LED_Gruen 15 // Gruene LED

// LED PWM Einstellungen
#define PWMfreq 5000 // 5 Khz Basisfrequenz für LED Anzeige #define PWMledChannelA 0

#define PWMledChannelB 1

#define PWMledChannelC 2

#define PWMresolution 8 // 8 Bit Resolution für LED PWM

//Sonstige Definitionen
#define ADCAttenuation ADC_ATTEN_DB_11 //ADC_ATTEN_DB_11 = 0-3,6V Dämpfung ADC (ADC Erweiterung #define MoisureSens_Poll_Interval 300000 // Intervall zwischen zwei Bodenfeuchtemessungen in Millisekunden -> alle 5 Minuten Datenpaket an Handy senden

#define DHT_Poll_Interval 400000 // Intervall zwischen zwei Temeperatur und Luftfreuchtemessungen in Millisekunden -> alle 6 Minuten Datenpaket an Handy senden

#define MaxSensors 6 | // Maximale Anzahl an anschließbaren FeuchteSensoren

#define StartInit true

#define RunTime false

#define Sens_Calib true

#define Sens_NOTCalib false

#define EEPROM_SIZE 512 | // Größe des Internen EEPROMS

// Blynk APP Definitionen
#define BLYNK_GREEN | "#23C48E"

#define BLYNK_BLUE | "#04C0F8"

#define BLYNK_YELLOW "#ED9D00"

#define BLYNK_RED | "#D3435C"

#define BLYNK_BLACK | "#000000"

#define BLYNK_PRINT Serial #define BLYNK_NO_BUILTIN

#define BLYNK_NO_FLOAT

//#define BLYNK_DEBUG

//DHT Konfiguration
#define DHTPIN 4 // Digital pin connected to the DHT sensor #define DHTTYPE DHT22 // DHT 22 (AM2302), AM2321 //#define DHTTYPE DHT21 // DHT 21 (AM2301)

struct MoistureSensorCalibrationData
{
int Data[MaxSensors*2] = {1651,2840,1652,2840,1653,2840,1654,2840,1655,2840,1656,2840}; // Calibration Data für Feuchtigkeitssensor. Bitte Projekt Text beachten und Werte ensprechend anpassen
// int Data[MaxSensors*2] = {0,0,0,0,0,0,0,0,0,0,0,0,}; // Calibration Data für Feuchtigkeitssensor. Bitte Projekt Text beachten und Werte ensprechend anpassen
byte StatusBorderPercentValues[MaxSensors*2][2]= { {10,50}, // Zweidimensinonales Array für Prozentgrenzwerte (Ampel) jeweils Einzeln pro Feuchtesensor (1 -6)
| | {10,50}, {10,50}, {10,50}, {10,50}, {10,50}};

String SensorName[MaxSensors+2] = {"Pflanze 1","Pflanze 2","Pflanze 3","Pflanze 4","Pflanze 5","Pflanze 6","Luftfeuchte","Temperatur"}; // Sensorname, der auch in der APP als Überschrift angezeigt wird

};

struct MoistureSensorData
{
int Percent[MaxSensors] = {0,0,0,0,0,0}; // Feuchtigkeitssensordaten in Prozent byte Old_Percent[MaxSensors] = {0,0,0,0,0,0}; // Vorherige _ Feuchtigkeitssensordaten in Prozent (Zweck: DatenMenge einsparen.)
bool DataValid [MaxSensors] = {false,false,false,false,false,false};
};

struct DHTSensorData
{
float Humidity = 0 ; // Luftfeuchtigkeitssensordaten in Prozent float Temperature = 0;
float Old_Humidity = 0 ; // Luftfeuchtigkeitssensordaten in Prozent float Old_Temperature = 0;
bool DataValid = false;
bool SensorEnabled = false;
};

DHT dht(DHTPIN, DHTTYPE); // DHP Instalz initalisieren

//Global Variables

char auth[] = "xxxxxxxxxxxxxxxxxxxxxxxxxxxxxxxx"; // Hier lt. Anleitung Auth Token dere Blynk App eintragen (E-Mail). // Deine WiFi Zugangsdaten.
char ssid[] = "Deine_WLAN_SSID"; | // Bitte an eigene WLAN SSID anpassen
char pass[] = "Dein _WLAN _Passwort!"; | // Bitte an eigene WLAN Passwort anpassen
MoistureSensorCalibrationData MCalib;
MoistureSensorData MMeasure;
DHTSensorData DHTMeasure;

byte AttachedMoistureSensors; // Detected Active Moisture Sensors (Count)
unsigned long Moisure_ServiceCall_Handler = 0; // Delay Variable for Delay between Moisure Readings unsigned long DHT_ServiceCall_Handler = 0; // Delay Variable for Delay between DHT Readings

void setup() {
pinMode(LED_Rot,OUTPUT);
pinMode(LED_Blau,OUTPUT);
pinMode(LED_Gruen,OUTPUT);
Serial.begin(115200); // initialize serial communication at 115200 bits per second: ledcSetup(PWMledChannelA, PWMfreq, PWMresolution);
ledcSetup(PWMledChannelB, PWMfreq, PWMresolution);
ledcSetup(PWMledChannelC, PWMfreq, PWMresolution);
ledcAttachPin(LED_Rot, PWMledChannelA); // attach the channel to the GPIO to be controlled ledcAttachPin(LED_Blau, PWMledChannelB);
ledcAttachPin(LED_Gruen, PWMledChannelC);
SetLedConfig(255,255,255);
Serial.println(F("Systemkonfiguration:"));
if (!EEPROM.begin(EEPROM_SIZE))
{
Serial.println(F("failed to initialise EEPROM")); } else
{ Serial.println(EEPROM_SIZE);
Serial.println(F(" Bytes EEPROM"));
}

AttachedMoistureSensors = DetectMoistureSensors(); Serial.print(AttachedMoistureSensors);
Serial.println(F(" Bodenfeuchtigkeitsensor(en)")); dht.begin();
DHTMeasure.SensorEnabled = Run_DHTSensor (StartInit); if (DHTMeasure.SensorEnabled)
{
Serial.println(F("1 DHT 22 Sensor"));
}
Serial.print(F("Verbindung zu WLAN"));
delay(500);
Blynk.begin(auth, ssid, pass); // Initalize WiFi-Connection over Blync Library Serial.println(F(" erfolgreich."));
SetLedConfig(0,0,0);
Init_Blynk_APP();
Run_MoistureSensors(StartInit);
for (int i = AttachedMoistureSensors;i < 6;i++) { Update_Blynk_APP(i,Sens_Calib); }; }

byte DetectMoistureSensors ()
{
#define MinSensorValue 100

byte Detected = 0;
for (int i = 0;i < MaxSensors;i++)
{
int MSensorRawValue = ReadMoistureSensor_Raw_Val(i);
if ( MSensorRawValue > MinSensorValue) { Detected++; } else {break;} }
if (Detected < 1)
{
Serial.println(F("Keine Bodenfeuchtigkeitssesoren erkannt. System angehalten.")); esp_deep_sleep_start();
while(1) {}
}
return Detected;
}

bool SetLedConfig(byte Red,byte Green,byte Blue) {
ledcWrite(PWMledChannelA, Red); // Rote LED ledcWrite(PWMledChannelB, Blue); // Blaue LED ledcWrite(PWMledChannelC, Green); // Gruene LED return true;
}

int ReadMoistureSensor_Raw_Val(byte Sensor)
{
int ReturnValue,i;
long sum = 0;
#define NUM_READS 6

adc1_config_width(ADC_WIDTH_BIT_12); //Range 0-4095 switch (Sensor)
{
case 0:
{
adc1_config_channel_atten(ADC1_CHANNEL_0,ADCAttenuation); for (i = 0; i < NUM_READS; i++){ // Averaging algorithm
sum += adc1_get_raw( ADC1_CHANNEL_0 ); //Read analog
}
ReturnValue = sum / NUM_READS;
break;
}
case 1:
{
adc1_config_channel_atten(ADC1_CHANNEL_3,ADCAttenuation); for (i = 0; i < NUM_READS; i++){ // Averaging algorithm
sum += adc1_get_raw( ADC1_CHANNEL_3 ); //Read analog
}
ReturnValue = sum / NUM_READS;
break;
}
case 2:
{
adc1_config_channel_atten(ADC1_CHANNEL_6,ADCAttenuation); for (i = 0; i < NUM_READS; i++){ // Averaging algorithm
sum += adc1_get_raw( ADC1_CHANNEL_6 ); //Read analog
}
ReturnValue = sum / NUM_READS;
break;
}
case 3:
{
adc1_config_channel_atten(ADC1_CHANNEL_7,ADCAttenuation); for (i = 0; i < NUM_READS; i++){ // Averaging algorithm
sum += adc1_get_raw( ADC1_CHANNEL_7 ); //Read analog
}
ReturnValue = sum / NUM_READS;
break;
}
case 4:
{
adc1_config_channel_atten(ADC1_CHANNEL_4,ADCAttenuation); for (i = 0; i < NUM_READS; i++){ // Averaging algorithm
sum += adc1_get_raw( ADC1_CHANNEL_4 ); //Read analog
}
ReturnValue = sum / NUM_READS;
break;
}
default:

{
adc1_config_channel_atten(ADC1_CHANNEL_5,ADCAttenuation); for (i = 0; i < NUM_READS; i++){ // Averaging algorithm
sum += adc1_get_raw( ADC1_CHANNEL_5 ); //Read analog
}
ReturnValue = sum / NUM_READS;
break;
}
}

return ReturnValue;
}

void Init_Blynk_APP()
{
Blynk.setProperty(V1,"label",MCalib.SensorName[0]); Blynk.setProperty(V2,"label",MCalib.SensorName[1]); Blynk.setProperty(V3,"label",MCalib.SensorName[2]); Blynk.setProperty(V4,"label",MCalib.SensorName[3]); Blynk.setProperty(V5,"label",MCalib.SensorName[4]); Blynk.setProperty(V6,"label",MCalib.SensorName[5]); Blynk.setProperty(V7,"label",MCalib.SensorName[6]); Blynk.setProperty(V8,"label",MCalib.SensorName[7]); }

void Update_Local_Display()
{
byte red1 = 0;
byte yellow1 = 0;
byte green1 = 0;
for (byte i = 0;i < AttachedMoistureSensors;i++) {
if (MMeasure.DataValid[i])
{
if ( MMeasure.Percent[i] > MCalib.StatusBorderPercentValues[i][1])
{
green1++;
} else if ( MMeasure.Percent[i] > MCalib.StatusBorderPercentValues[i][0]) {
yellow1++;
} else
{
red1++;
}
}
}
if (red1 > 0)
{ SetLedConfig(255,0,0); } else if (yellow1 > 0)
{ SetLedConfig(255,255,0); } else if (green1 > 0)
{ SetLedConfig(0,255,0); } else
{ SetLedConfig(0,0,255); }
}

void Update_Blynk_APP(byte Sensor,bool Calibrated) {
switch (Sensor)
{
case 0:
{
if ((MMeasure.DataValid[0]) & (Calibrated))
{
if ( MMeasure.Percent[0] > MCalib.StatusBorderPercentValues[0][1])
{
Blynk.setProperty(V1,"color",BLYNK_GREEN);
} else if ( MMeasure.Percent[0] > MCalib.StatusBorderPercentValues[0][0]) {
Blynk.setProperty(V1,"color",BLYNK_YELLOW);
} else
{
Blynk.setProperty(V1,"color",BLYNK_RED);
}
delay(100);
Blynk.virtualWrite(V1,MMeasure.Percent[0]); } else

{
if (Calibrated)
{
Blynk.setProperty(V1,"label","Deaktiviert"); delay(100);
Blynk.virtualWrite(V1,0);
delay(100);
Blynk.setProperty(V1,"color",BLYNK_BLACK); }
else
{
Blynk.virtualWrite(V1,0);
delay(100);
Blynk.setProperty(V1,"color",BLYNK_BLUE); }
}
break;
}
case 1:
{
if ((MMeasure.DataValid[1]) & (Calibrated))
{
if ( MMeasure.Percent[1] > MCalib.StatusBorderPercentValues[1][1])
{
Blynk.setProperty(V2,"color",BLYNK_GREEN);
} else if ( MMeasure.Percent[1] > MCalib.StatusBorderPercentValues[1][0]) {
Blynk.setProperty(V2,"color",BLYNK_YELLOW);
} else
{
Blynk.setProperty(V2,"color",BLYNK_RED);
}
delay(100);
Blynk.virtualWrite(V2,MMeasure.Percent[1]); } else
{
if (Calibrated)
{
Blynk.setProperty(V2,"label","Deaktiviert"); delay(100);
Blynk.virtualWrite(V2,0);
delay(100);
Blynk.setProperty(V2,"color",BLYNK_BLACK); }
else
{
Blynk.virtualWrite(V2,0);
delay(100);
Blynk.setProperty(V3,"color",BLYNK_BLUE); }
}
break;
}
case 2:
{
if ((MMeasure.DataValid[2]) & (Calibrated))
{
if ( MMeasure.Percent[2] > MCalib.StatusBorderPercentValues[2][1])
{
Blynk.setProperty(V3,"color",BLYNK_GREEN);
} else if ( MMeasure.Percent[2] > MCalib.StatusBorderPercentValues[2][0]) {
Blynk.setProperty(V3,"color",BLYNK_YELLOW);
} else
{
Blynk.setProperty(V3,"color",BLYNK_RED);
}
delay(100);
Blynk.virtualWrite(V3,MMeasure.Percent[2]); } else
{
if (Calibrated)
{
Blynk.setProperty(V3,"label","Deaktiviert"); delay(100);
Blynk.virtualWrite(V3,0);
delay(100);

Blynk.setProperty(V3,"color",BLYNK_BLACK); }
else
{
Blynk.virtualWrite(V3,0);
delay(100);
Blynk.setProperty(V3,"color",BLYNK_BLUE); }
}
break;
}
case 3:
{
if ((MMeasure.DataValid[3]) & (Calibrated))
{
if ( MMeasure.Percent[3] > MCalib.StatusBorderPercentValues[3][1])
{
Blynk.setProperty(V4,"color",BLYNK_GREEN);
} else if ( MMeasure.Percent[3] > MCalib.StatusBorderPercentValues[3][0]) {
Blynk.setProperty(V4,"color",BLYNK_YELLOW);
} else
{
Blynk.setProperty(V4,"color",BLYNK_RED);
}
delay(100);
Blynk.virtualWrite(V4,MMeasure.Percent[3]); } else
{
if (Calibrated)
{
Blynk.setProperty(V4,"label","Deaktiviert"); delay(100);
Blynk.virtualWrite(V4,0);
delay(100);
Blynk.setProperty(V4,"color",BLYNK_BLACK); }
else
{
Blynk.virtualWrite(V4,0);
delay(100);
Blynk.setProperty(V4,"color",BLYNK_BLUE); }
}
break;
}
case 4:
{
if ((MMeasure.DataValid[4]) & (Calibrated))
{
if ( MMeasure.Percent[4] > MCalib.StatusBorderPercentValues[4][1])
{
Blynk.setProperty(V5,"color",BLYNK_GREEN);
} else if ( MMeasure.Percent[4] > MCalib.StatusBorderPercentValues[4][0]) {
Blynk.setProperty(V5,"color",BLYNK_YELLOW);
} else
{
Blynk.setProperty(V5,"color",BLYNK_RED);
}
delay(100);
Blynk.virtualWrite(V5,MMeasure.Percent[4]); } else
{
if (Calibrated)
{
Blynk.setProperty(V5,"label","Deaktiviert"); delay(100);
Blynk.virtualWrite(V5,0);
delay(100);
Blynk.setProperty(V5,"color",BLYNK_BLACK); }
else
{
Blynk.virtualWrite(V5,0);
delay(100);
Blynk.setProperty(V5,"color",BLYNK_BLUE);

}
}
break;
}
case 5:
{
if ((MMeasure.DataValid[5]) & (Calibrated))
{
if ( MMeasure.Percent[5] > MCalib.StatusBorderPercentValues[5][1])
{
Blynk.setProperty(V6,"color",BLYNK_GREEN);
} else if ( MMeasure.Percent[5] > MCalib.StatusBorderPercentValues[5][0]) {
Blynk.setProperty(V6,"color",BLYNK_YELLOW);
} else
{
Blynk.setProperty(V6,"color",BLYNK_RED);
}
delay(100);
Blynk.virtualWrite(V6,MMeasure.Percent[5]); } else
{
if (Calibrated)
{
Blynk.setProperty(V6,"label","Deaktiviert"); delay(100);
Blynk.virtualWrite(V6,0);
delay(100);
Blynk.setProperty(V6,"color",BLYNK_BLACK); }
else
{
Blynk.virtualWrite(V6,0);
delay(100);
Blynk.setProperty(V6,"color",BLYNK_BLUE); }
}
break;
}
case 6:
{
if (DHTMeasure.DataValid)
{
Blynk.virtualWrite(V7,DHTMeasure.Humidity); } else
{
Blynk.setProperty(V7,"label","Deaktiviert"); delay(100);
Blynk.virtualWrite(V7,0);
delay(100);
Blynk.setProperty(V7,"color",BLYNK_BLACK); }
break;
}
case 7:
{
if (DHTMeasure.DataValid)
{
Blynk.virtualWrite(V8,DHTMeasure.Temperature); } else
{
Blynk.setProperty(V8,"label","Deaktiviert"); delay(100);
Blynk.virtualWrite(V8,0);
delay(100);
Blynk.setProperty(V8,"color",BLYNK_BLACK); }
break;
}

} // End Switch
}

void Get_Moisture_DatainPercent() {
byte CalibDataOffset = 0;

for (byte i = 0;i < AttachedMoistureSensors;i++)
{
CalibDataOffset = i *2;
int RawMoistureValue = ReadMoistureSensor_Raw_Val(i);
if ((MCalib.Data[CalibDataOffset] == 0) || (MCalib.Data[CalibDataOffset+1] == 0)) // MinADC Value maxADC ADC Value {
MMeasure.Percent[i] = RawMoistureValue;
MMeasure.DataValid[i] = false;
} else
{
RawMoistureValue= MCalib.Data[CalibDataOffset+1] - RawMoistureValue; RawMoistureValue=MCalib.Data[CalibDataOffset] + RawMoistureValue;
MMeasure.Percent[i] = map(RawMoistureValue,MCalib.Data[CalibDataOffset],MCalib.Data[CalibDataOffset+1], 0, 100);
if ((MMeasure.Percent[i] > 100 ) | (MMeasure.Percent[i] < 0 ))
{
MMeasure.Percent[i] = RawMoistureValue;
MMeasure.DataValid[i] = false;
} else { MMeasure.DataValid[i] = true; } }
}
return ;
}

void Run_MoistureSensors (bool Init) // HauptFunktion zum Betrieb der Bodenfeuchtesensoren {
byte MinSensValue = 100;
if ((millis() - Moisure_ServiceCall_Handler >= MoisureSens_Poll_Interval) | (Init))
{
Moisure_ServiceCall_Handler = millis();
Get_Moisture_DatainPercent();
for (int i = 0;i < AttachedMoistureSensors;i++) {
if (MMeasure.DataValid[i])
{
if (MMeasure.Percent[i] != MMeasure.Old_Percent[i])
{
MMeasure.Old_Percent[i] = MMeasure.Percent[i];
if (MMeasure.Percent[i] < MinSensValue ) { MinSensValue = MMeasure.Percent[i]; }; Serial.print(F("Feuchtigkeitswert Sensor "));
Serial.print(i);
Serial.print(F(" in Prozent :"));
Serial.print(MMeasure.Percent[i]);
Serial.println(F(" %"));
Update_Blynk_APP(i,Sens_Calib); // Aktualisiere Handywerte }
} else
{
Update_Blynk_APP(i,Sens_NOTCalib); // Aktualisiere Handywerte Serial.print(F("Sensor "));
Serial.print(i);
Serial.print(F(" nicht kalibiert. Bitte kalibrieren. Rohdatenwert:")); Serial.println(MMeasure.Percent[i]);
}
}
Update_Local_Display(); // Aktualisiere lokales Pflanzenwächter Display (Led) }
}

bool Run_DHTSensor (bool Init) //
{
if ((millis() - DHT_ServiceCall_Handler >= DHT_Poll_Interval) | (Init))
{
DHT_ServiceCall_Handler = millis();
DHTMeasure.Humidity = dht.readHumidity();
DHTMeasure.Temperature = dht.readTemperature(false); // Read temperature as Celsius (isFahrenheit = true) if (isnan(DHTMeasure.Humidity) || isnan(DHTMeasure.Temperature) )
{
Serial.println(F("Failed to read from DHT sensor!"));
DHTMeasure.DataValid = false;
return false;
}
DHTMeasure.DataValid = true;
if (DHTMeasure.Humidity != DHTMeasure.Old_Humidity) {
DHTMeasure.Old_Humidity = DHTMeasure.Humidity;

Update_Blynk_APP(6,true); // Luftfeuchteanzeige
}
if (DHTMeasure.Temperature != DHTMeasure.Old_Temperature) {
DHTMeasure.Old_Temperature = DHTMeasure.Temperature; Update_Blynk_APP(7,true); // Temperaturanzeige
}

}
return true;
}

// Main Loop
void loop()
{
Run_MoistureSensors(RunTime);
if (DHTMeasure.SensorEnabled) { Run_DHTSensor(RunTime); } Blynk.run(); // Execute Blync Basic- Functions
}

## Weitere unbedingt anzupassende Parameter sind nicht hinzugekommen, da der DHT 22 und auch der DHT 11 Sensor eine interne Werte Kalibrierung hat, die keiner

weiteren Anpassung mehr Bedarf.

## Nachdem wir den Code nun angepasst und auf unseren ESP hochgeladen haben und sich unser ESP erfolgreich in das WLAN eingeloggt hat (Weiße LED geht aus) müssen

wir auch in diesem Teil wieder unsere APP erweitern.

## Dazu fügen wir in unsere APP zwei weitere „LEVEL H“ Elemente hinzu und konfigurieren das erste Element für die Luftfeuchte wie folgt:

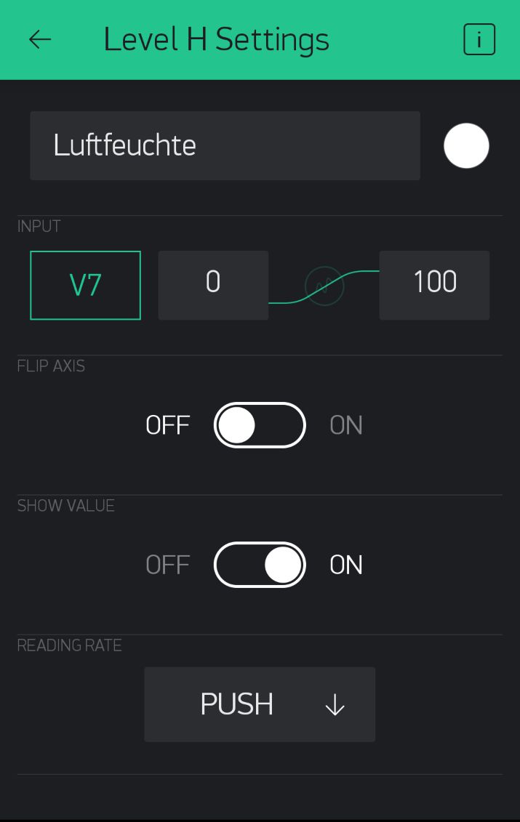
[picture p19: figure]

## - Farbe: Weiß - Input Pin: V7 (virtuell) - Minimum Wert:0 - Maximum Wert: 100 - Reading Rate: PUSH

## Das zweite „Level H“ Element für die Temperatur konfigurieren wie folgt:

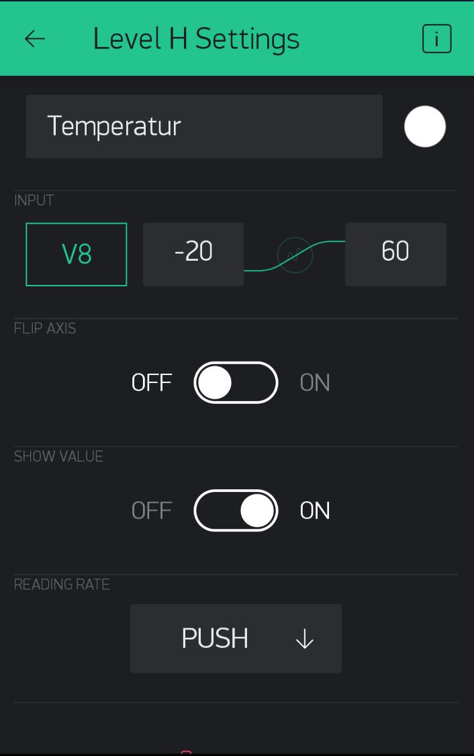
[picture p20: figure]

## - Farbe: Weiß - Input Pin: V8 (virtuell) - Minimum Wert: -20 - Maximum Wert: 60 - Reading Rate: PUSH

## Anschließend sollte unsere Pflanzen App wie folgt aussehen:

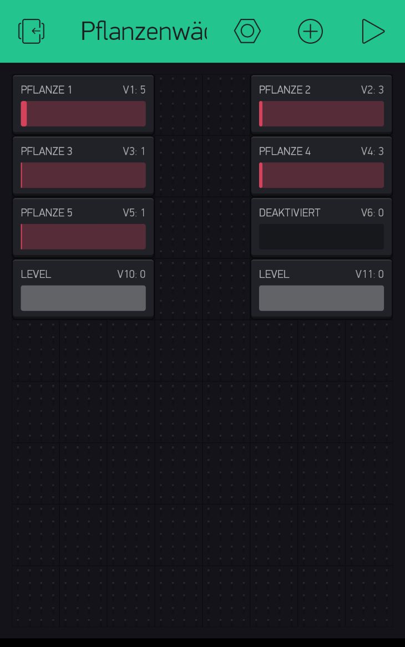
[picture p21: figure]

## Nach drücken des „Start“ Buttons bekommen wir nun in der APP neben den aktuellen Bodenfeuchtesensorwerten auch die aktuelle Temperatur und Luftfeuchtigkeit dank

unserem DHT Sensor angezeigt.
Ich wünsche viel Spaß beim Nachbauen, und bis zum nächsten Mal.

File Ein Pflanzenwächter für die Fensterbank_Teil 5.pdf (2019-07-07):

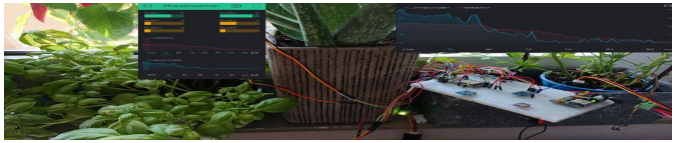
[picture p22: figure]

# Pflanzenwächter für die Fensterbank Teil 5 – Beleuchtungsstärkenmessung

In diesem Teil der Reihe werde ich noch einmal das wichtigste aus den vorherigen Teilen zusammenfassen. Wir haben Rückblickend schon einige Änderungen und Ergänzungen unseres Pflanzenwächters vorgenommen. Beispielsweise haben wir die Anzahl der Bodenfeuchtesensoren um 6 erweitert und einen kombinierten Temperatur-

und Luftfeuchtesensor hinzugefügt. Für Pflanzen sind das schon mal eine gute Basis.

## Es fehlt jedoch noch für unsere Pflanzenwelt ein weiterer wichtiger ja unverzichtbarer Umweltfaktor. Dies ist das Licht, im speziellen die Beleuchtungsstärke! Genmessen

wird die Beleuchtungsstärke in der Einheit Lux.

Die meisten Pflanzen fühlen sich im Beleuchtungsstärkenbereich von 300-1500 Lux (je nach Pflanzentyp) am wohlsten. Dies wollen wir natürlich berücksichtigen und mit unserem Pflanzenwächter die Helligkeit in Lux jederzeit im Auge behalten. Dazu erfassen wir die Beleuchtungsstärke in der Einheit Lux und stellen diese in gewohnter

Art und Weise auf dem Handydisplay als Informationswert dar.

## Für diese Aufgabe eignet sich, in unserem Fall, der Beleuchtungsstärkensensor

BH1750, da dieser zum einen mit den 3,3 Volt Datenpegeln des ESP32 kompatibel ist,

## als auch die Beleuchtungsstärke als Datenpaket über die I2C Schnittstelle direkt in Lux

Einheit an unseren ESP weitergibt.
Bestellbar ist der Lichtsensor z.B. bei AZ-Delivery Shop als Modul GY-302.

## Wenn euch weitere Details zu dem Modul interessieren, findet ihr z.B. hier weitere

Informationen.

## Der BH1750 hat einen sehr großen Messbereich und die Auflösung kann grundsätzlich

per Konfigurationsparameter zwischen 0,5 Lux, 1 Lux und 4 Lux gewählt werden. Für unser Projekt wählen wir die mittlere Auflösung von 1 Lux aus.

## Mit Hinzufügen des Lichtsensors haben wir unsere benötigten Sensoren jetzt final für das Projekt zusammen

## Hier findet Ihr die vorhergehenden Pflanzenwächterteile, deren Studium ich empfehlen

möchte, | da | wichtige | Informationen, | Z.B. | über | die | Kalibrierung | der

## Bodenfeuchtesensoren darin enthalten sind:

## - Teil 1 - Teil 2 - Teil 3 - Teil 4

## Kommen wir zurück auf die wichtige Teileliste. Ihr findet alle relevante Teile dieses Projektes, die ihr zum Nachbau benötigt, in folgender Teileliste:

Anzahl | Beschreibung | Anmerkung
1 | DHT 22
| DHT 11 | Alternativ zu DHT 22
1 | KY-016 LED RGB Modul
1 | ESP-32 Dev Kit C
6 | Bodenfeuchte Sensor Modul V1.2
1 | MB102 Netzteil Adapter | Für Breadboardaufbau
1 | Modul GY-302 | Beleuchtungsstärkensensor
12 | Wiederstände laut Beschreibung

## Wir schauen wir uns den aktualisierten Schaltplan/Verdrahtungsplan des Pflanzenwächters an:

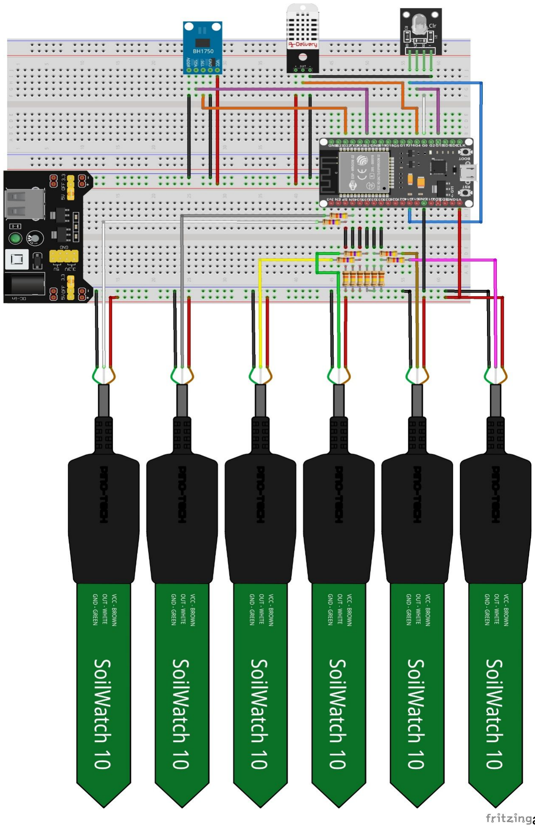
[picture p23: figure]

an:

## Wir erkennen darauf den neu hinzugekommen Lichtsensor BH1570. Wir verbinden die Peripherie wie folgt:

## RGB_Led Modul

RGB -Led Anode | ESP32 Pin
Rot | 0
Grün | 15
Blau | 14
l

## Bodenfeuchtesensoren

Feuchtesensor | ESP32 Pin
1 | SP
2 | SN
3 | 34
4 | 35
5 | 32
6 | 33

## Temperatur/Luftfeuchtesensor DHT 22

PIN | ESP32 Pin
DATA /IN OUT | 4

## Beleuchtungsstärkensensor BH1570

BH1570 PIN | ESP32 Pin
SDA | 21
SCL | 22
ADDR | GND

## Nachdem wir uns von der korrekten Verdrahtung überzeugt haben laden folgenden Code auf unseren ESP hoch:

#include <driver/adc.h> // Build In Library. No external Library needed //#include <esp_wifi.h>

#include <WiFi.h>

#include <WiFiClient.h>

#include <ESPmDNS.h>

#include <BlynkSimpleEsp32.h> #include <EEPROM.h>

#include <Preferences.h>

#include <Wire.h>

#include "DHT.h" // REQUIRES the following Arduino libraries: //- DHT Sensor Library: https://github.com/adafruit/DHT-sensor-library//- Adafruit Unified Sensor Lib: https://github.com/adafruit/Adafruit_Sensor

// Portedefinierung RGB LED Modul
#define LED_Rot | 0 | // Rote LED

#define LED_Blau 14 // Blaue LED #define LED_Gruen 15 // Gruene LED

// I2C Port Definitionen
#define SDA1 21

#define SCL1 22

// LED PWM Einstellungen
#define PWMfreq 5000 // 5 Khz Basisfrequenz für LED Anzeige #define PWMledChannelA 0

#define PWMledChannelB 1

#define PWMledChannelC 2

#define PWMresolution 8 // 8 Bit Resolution für LED PWM

//Zeit / Timing Definitionen für Sensorabfragen
#define ADCAttenuation ADC_ATTEN_DB_11 | // ADC_ATTEN_DB_11 = 0-3,6V Dämpfung ADC (ADC Erweiterung

#define MoisureSens_Poll_MinInterval 3600 | // Minimales Messwertübertragungsintervall zwischen zwei

Bodenfeuchtemessungen in Sekunden.
#define DHT_Poll_MinInterval 2700 | // Minimales Messwertübertragungsintervall zwischen zwei Temperatur und

Luftfeuchikeitsemessungen in Sekunden.
#define BH_Poll_MinInterval 1800 | // Minimales Messwertübertragungsintervall zwischen zwei Lichtstärkeabfragen in

Sekunden.
#define DEBUG | // Bei definierung werden verschiedene Informationen und Messwerte auf der Seriellen

Schnittstelle ausgegeben. Bitte löschen vor produktivem Einsatz !
#define MaxSensors 6 | // Maximale Anzahl an anschließbaren FeuchteSensoren

#define MinSensorValue 500 | // Mnidest AD Wert, um einen Sensoreingangskanale (1-6) als "Aktiv" an das System

zu melden. (Feuchtesensor ist angeschlossen während der Bootphase)
#define StartInit true

#define RunTime false

#define Sens_Calib true

#define Sens_NOTCalib false

#define EEPROM_SIZE 512 | // Definition Größe des Internen EEPROMS

// Blynk APP Definitionen
#define BLYNK_GREEN | "#23C48E"

#define BLYNK_BLUE | "#04C0F8"

#define BLYNK_YELLOW "#ED9D00"

#define BLYNK_RED | "#D3435C"

#define BLYNK_BLACK | "#000000"

#define BLYNK_WHITE | "#FFFFFF"

#define BLYNK_PRINT Serial 1 #define BLYNK_NO_BUILTIN

#define BLYNK_NO_FLOAT

//#define BLYNK_DEBUG

//DHT Konfiguration
#define DHTPIN 4 | // Digital pin connected to the DHT sensor

#define DHTTYPE DHT22 | // DHT 22 (AM2302), AM2321

//#define DHTTYPE DHT21 | // Falls im eingenen Projekt ein DHT 21 (AM2301) verwendet wird, bitte diee
EInstellung definieren

struct SystemRunParameters
{
int Data[MaxSensors*2] = {0,0,0,0,0,0,0,0,0,0,0,0,}; // Calibration Data für Feuchtigkeitssensor. Bitte Projekt Text beachten und Werte ensprechend anpassen
byte StatusBorderPercentValues[MaxSensors*2][2]= { {10,50}, // Zweidimensinonales Array für Prozentgrenzwerte (Ampel) jeweils Einzeln pro Feuchtesensor (1 -6)
{10,50},
{10,50},
{10,50},
{10,50},
{10,50}};
String SensorName[MaxSensors+3] = {"Pflanze 1","Pflanze 2","Pflanze 3","Pflanze 4","Pflanze 5","Pflanze 6","Luftfeuchte","Temperatur","Lichtstärke"}; // Sensorname, der auch in der APP als Überschrift angezeigt wird
};

struct MoistureSensorData
{
int Percent[MaxSensors] = {0,0,0,0,0,0}; // Feuchtigkeitssensordaten in Prozent
byte Old_Percent[MaxSensors] = {0,0,0,0,0,0}; // Vorherige _ Feuchtigkeitssensordaten in Prozent (Zweck: DatenMenge einsparen.)
bool DataValid [MaxSensors] = {false,false,false,false,false,false};
};

struct DHTSensorData
{
float Humidity = 0 ; // Luftfeuchtigkeitssensordaten in Prozent float Temperature = 0;
float Old_Humidity = 0 ; // Luftfeuchtigkeitssensordaten in Prozent float Old_Temperature = 0;
bool DataValid = false;
bool SensorEnabled = false;
};

struct BHLightSensorData
{
int Lux = 0 ; | // Lichtstärke in Lux
int Old_Lux = 0 ; | // Lichtstärke in Lux
bool DataValid = false;
bool SensorEnabled = false;
};

DHT dht(DHTPIN, DHTTYPE); // DHT Sensor Instanz initalisieren

TwoWire I2CWire = TwoWire(0);

//Global Variables

char auth[] = "xxxxxxxxxxxxxxxxxxxxxxxxxxxxxxxx"; // Hier lt. Anleitung Auth Token dere Blynk App eintragen (E-Mail). // Deine WiFi Zugangsdaten.
char ssid[] = "Deine_WLAN_SSID"; | // Bitte an eigene WLAN SSID anpassen
char pass[] = "Dein _WLAN _Passwort!"; | // Bitte an eigene WLAN Passwort anpassen
char ESPName[] = "PlantSensor1";

SystemRunParameters SysConfig;
MoistureSensorData MMeasure; DHTSensorData DHTMeasure;
BHLightSensorData BHMeasure;
byte AttachedMoistureSensors = 0; | // Detected Active Moisture Sensors (Count)
byte BH1750I2CAddress = 0; | // Detected BH1750 I2C Address
bool Connected2Blynk = false; | // Bool Variable. Stores the Connectionstate to the Blynk Cloud
unsigned long Moisure_ServiceCall_Handler = 0; // Delay Variable for Delay between Moisure Readings
unsigned long DHT_ServiceCall_Handler = 0; | // Delay Variable for Delay between DHT Readings
unsigned long BH_ServiceCall_Handler = 0; | // Delay Variable for Delay between BH1750 Readings
unsigned long chipid;

void setup() {
pinMode(LED_Rot,OUTPUT);
pinMode(LED_Blau,OUTPUT);
pinMode(LED_Gruen,OUTPUT);
Serial.begin(115200); | // initialize serial communication at 115200 bits per second:
I2CWire.begin(SDA1,SCL1,400000); // join i2c bus (address optional for master) //chipid=ESP.getEfuseMac(); //The chip ID is essentially its MAC address(length: 6 bytes). //sprintf(ESPName, "%d%d%d%d%d%d%d%d%d%d%d%d%d%d%d%d%d", chipid); ledcSetup(PWMledChannelA, PWMfreq, PWMresolution);
ledcSetup(PWMledChannelB, PWMfreq, PWMresolution);
ledcSetup(PWMledChannelC, PWMfreq, PWMresolution);
ledcAttachPin(LED_Rot, PWMledChannelA); // attach the channel to the GPIO to be controlled ledcAttachPin(LED_Blau, PWMledChannelB);
ledcAttachPin(LED_Gruen, PWMledChannelC);
SetLedConfig(255,255,255);
#ifdef DEBUG

Serial.print(F("Verbindung zu WLAN")); #endif
WiFi.disconnect();
WiFi.setHostname(ESPName);
// esp_wifi_set_mode(WIFI_MODE_STA); WiFi.mode(WIFI_STA);
WiFi.begin(ssid, pass);
WiFi.setSleep(false);
if(WiFi.waitForConnectResult() != WL_CONNECTED) {
while (WiFi.status() != WL_CONNECTED)
{
delay(1000);
WiFi.begin(ssid, pass); // try again, if first Connect is unsuccessful #ifdef DEBUG
Serial.print(F("."));
#endif

}
}
#ifdef DEBUG

Serial.println(F(" erfolgreich.")); Serial.print(F("IP Address: ")); Serial.println(WiFi.localIP()); Serial.print(F("Hostname: ")); Serial.println(ESPName);
#endif

if (!MDNS.begin(ESPName))
{
Serial.println("Error setting up MDNS responder!"); }
MDNS.addService("plant", "tcp", 400);

Blynk.config(auth); // in place of Blynk.begin(auth, ssid, pass); while (Blynk.connect() == false) {
delay(500);
Serial.print(".");
}

#ifdef DEBUG

Serial.println(F("Systemkonfiguration:")); #endif
if (EEPROM.begin(EEPROM_SIZE)) {
#ifdef DEBUG

Serial.print(EEPROM_SIZE); Serial.println(F(" Bytes EEPROM")); #endif
}
Run_MoistureSensors(StartInit);
#ifdef DEBUG

Serial.print(AttachedMoistureSensors); Serial.println(F(" Bodenfeuchtigkeitsensor(en)"));

#endif

dht.begin();
DHTMeasure.SensorEnabled = Run_DHTSensor (StartInit); if (DHTMeasure.SensorEnabled)
{
#ifdef DEBUG

Serial.println(F("1 DHT 22 Sensor"));
#endif

}
BHMeasure.SensorEnabled = Run_BH1750Sensor(StartInit); if (BHMeasure.SensorEnabled)
{
#ifdef DEBUG

Serial.println(F("1 B1750 Light Sensor")); #endif
}
}

void CheckConnection(){
Connected2Blynk = Blynk.connected();
if(!Connected2Blynk){
Serial.println("Not connected to Blynk server");
Blynk.connect(3333); // timeout set to 10 seconds and then continue without Blynk }
else{
Serial.println("Connected to Blynk server");
}
}

bool Run_BH1750Sensor (bool Init) // Runtime Funktion für den BH170 Lichtsensor {
byte ec;
if ((millis() - BH_ServiceCall_Handler >= BH_Poll_MinInterval *1000) | (Init))
{
BH_ServiceCall_Handler = millis();
if (Init)
{
bool BH1750Detected = false; I2CWire.beginTransmission(35); ec=I2CWire.endTransmission(true); if(ec==0)
{
BH1750Detected = true;
BH1750I2CAddress = 35; // BH1750 I2C Adresse ist DEC 35 } else
{
I2CWire.beginTransmission(92); ec=I2CWire.endTransmission(true); if(ec==0)
{
BH1750Detected = true;
BH1750I2CAddress = 92; // BH1750 I2C Adresse ist DEC 92

}
}
if (BH1750Detected)
{
// Intialize Sensor
I2CWire.beginTransmission(BH1750I2CAddress); I2CWire.write(0x01); // Turn it on before we can reset it I2CWire.endTransmission();

I2CWire.beginTransmission(BH1750I2CAddress); I2CWire.write(0x07); // Reset I2CWire.endTransmission();

I2CWire.beginTransmission(BH1750I2CAddress);
I2CWire.write(0x10); // Continuously H-Resolution Mode ( 1 lux Resolution) Weitere Modis möglich, gemäß Datenblatt //I2CWire.write(0x11); // Continuously H-Resolution Mode 2 ( 0.5 lux Resolution)
//I2CWire.write(0x20); // One Time H-Resolution Mode ( 1 lux Resolution)
//I2CWire.write(0x21); // One Time H-Resolution Mode2 ( 0.5 lux Resolution)
I2CWire.endTransmission();

Blynk.setProperty(V9,"color",BLYNK_WHITE); Blynk.setProperty(V9,"label",SysConfig.SensorName[8]); } else
{
Blynk.setProperty(V9,"label","Deaktiviert"); Blynk.setProperty(V9,"color",BLYNK_BLACK); Blynk.virtualWrite(V9,0);
return BH1750Detected;
}
}
I2CWire.beginTransmission(BH1750I2CAddress); ec=I2CWire.endTransmission(true);
if(ec==0)
{
I2CWire.requestFrom(BH1750I2CAddress, 2);
BHMeasure.Lux = I2CWire.read();
BHMeasure.Lux <<= 8; | // Verschieben der unteren 8 Bits in die höhreren 8 Bits der 16 Bit breiten Zahl
BHMeasure.Lux |= I2CWire.read();
BHMeasure.Lux = BHMeasure.Lux / 1.2;
BHMeasure.DataValid = true;
if (BHMeasure.Lux != BHMeasure.Old_Lux)
{
BHMeasure.Old_Lux = BHMeasure.Lux; Update_Blynk_APP(8,true); // Lichtstärkeanzeige in Lux aktualisieren #ifdef DEBUG
Serial.print ("Lichtstärke in Lux :");
Serial.println (BHMeasure.Lux);
#endif

}
} else
{
BHMeasure.DataValid = false;

BHMeasure.SensorEnabled = false; Blynk.setProperty(V9,"color",BLYNK_BLUE); }
}
return true;
}

bool Run_DHTSensor (bool Init) // Runtime Funktion für den DHT Temp und Luftfeuchtesensor {
if ((millis() - DHT_ServiceCall_Handler >= DHT_Poll_MinInterval *1000) | (Init))
{
DHT_ServiceCall_Handler = millis();
DHTMeasure.Humidity = dht.readHumidity();
DHTMeasure.Temperature = dht.readTemperature(false); // Read temperature as Celsius (isFahrenheit = true) if (Init)
{
if (isnan(DHTMeasure.Humidity) || isnan(DHTMeasure.Temperature))
{
Blynk.setProperty(V7,"label","Deaktiviert"); Blynk.setProperty(V8,"label","Deaktiviert"); Blynk.virtualWrite(V7,0);
Blynk.virtualWrite(V8,-20); Blynk.setProperty(V7,"color",BLYNK_BLACK); Blynk.setProperty(V8,"color",BLYNK_BLACK); DHTMeasure.DataValid = false;
return false;
} else
{
Blynk.setProperty(V7,"color",BLYNK_WHITE); Blynk.setProperty(V7,"label",SysConfig.SensorName[6]); Blynk.setProperty(V8,"color",BLYNK_WHITE); Blynk.setProperty(V8,"label",SysConfig.SensorName[7]); DHTMeasure.DataValid = true;
DHTMeasure.Old_Humidity = DHTMeasure.Humidity; Update_Blynk_APP(6,true); // Luftfeuchteanzeige DHTMeasure.Old_Temperature = DHTMeasure.Temperature; Update_Blynk_APP(7,true); // Temperaturanzeige
return true;
}
}
if (isnan(DHTMeasure.Humidity) || isnan(DHTMeasure.Temperature)) {
Blynk.setProperty(V7,"color",BLYNK_BLUE); Blynk.setProperty(V8,"color",BLYNK_BLUE); DHTMeasure.DataValid = false; DHTMeasure.SensorEnabled = false; return false;
}
DHTMeasure.DataValid = true;
if (DHTMeasure.Humidity != DHTMeasure.Old_Humidity) {
DHTMeasure.Old_Humidity = DHTMeasure.Humidity;

Update_Blynk_APP(6,true); // Luftfeuchteanzeige
}
if (DHTMeasure.Temperature != DHTMeasure.Old_Temperature) {
DHTMeasure.Old_Temperature = DHTMeasure.Temperature; Update_Blynk_APP(7,true); // Temperaturanzeige
}
}
return true;
}

bool SetLedConfig(byte Red,byte Green,byte Blue) {
ledcWrite(PWMledChannelA, Red); // Rote LED ledcWrite(PWMledChannelB, Blue); // Blaue LED ledcWrite(PWMledChannelC, Green); // Gruene LED return true;
}

int ReadMoistureSensor_Raw_Val(byte Sensor) {
int ReturnValue,i;
long sum = 0;
#define NUM_READS 6

adc1_config_width(ADC_WIDTH_BIT_12); //Range 0-4095 switch (Sensor)
{
case 0:
{
adc1_config_channel_atten(ADC1_CHANNEL_0,ADCAttenuation); for (i = 0; i < NUM_READS; i++){ // Averaging algorithm
sum += adc1_get_raw( ADC1_CHANNEL_0 ); //Read analog
}
ReturnValue = sum / NUM_READS;
break;
}
case 1:
{
adc1_config_channel_atten(ADC1_CHANNEL_3,ADCAttenuation); for (i = 0; i < NUM_READS; i++){ // Averaging algorithm
sum += adc1_get_raw( ADC1_CHANNEL_3 ); //Read analog
}
ReturnValue = sum / NUM_READS;
break;
}
case 2:
{
adc1_config_channel_atten(ADC1_CHANNEL_6,ADCAttenuation); for (i = 0; i < NUM_READS; i++){ // Averaging algorithm
sum += adc1_get_raw( ADC1_CHANNEL_6 ); //Read analog
}
ReturnValue = sum / NUM_READS;

break;
}
case 3:
{
adc1_config_channel_atten(ADC1_CHANNEL_7,ADCAttenuation); for (i = 0; i < NUM_READS; i++){ // Averaging algorithm
sum += adc1_get_raw( ADC1_CHANNEL_7 ); //Read analog
}
ReturnValue = sum / NUM_READS;
break;
}
case 4:
{
adc1_config_channel_atten(ADC1_CHANNEL_4,ADCAttenuation); for (i = 0; i < NUM_READS; i++){ // Averaging algorithm
sum += adc1_get_raw( ADC1_CHANNEL_4 ); //Read analog
}
ReturnValue = sum / NUM_READS;
break;
}
default:
{
adc1_config_channel_atten(ADC1_CHANNEL_5,ADCAttenuation); for (i = 0; i < NUM_READS; i++){ // Averaging algorithm
sum += adc1_get_raw( ADC1_CHANNEL_5 ); //Read analog
}
ReturnValue = sum / NUM_READS;
break;
}
}

return ReturnValue;
}

void Update_Local_Display() {
byte red1 = 0;
byte yellow1 = 0;
byte green1 = 0;
for (byte i = 0;i < AttachedMoistureSensors;i++) {
if (MMeasure.DataValid[i])
{
if ( MMeasure.Percent[i] > SysConfig.StatusBorderPercentValues[i][1])
{
green1++;
} else if ( MMeasure.Percent[i] > SysConfig.StatusBorderPercentValues[i][0]) {
yellow1++;
} else
{

red1++;
}
}
}
if (red1 > 0)
{ SetLedConfig(255,0,0); } else if (yellow1 > 0)
{ SetLedConfig(255,255,0); } else if (green1 > 0)
{ SetLedConfig(0,255,0); } else
{ SetLedConfig(0,0,255); }
}

void Update_Blynk_APP(byte Sensor,bool Calibrated) {
switch (Sensor)
{
case 0:
{
if ((MMeasure.DataValid[0]) & (Calibrated))
{
if ( MMeasure.Percent[0] > SysConfig.StatusBorderPercentValues[0][1])
{
Blynk.setProperty(V1,"color",BLYNK_GREEN);
} else if ( MMeasure.Percent[0] > SysConfig.StatusBorderPercentValues[0][0]) {
Blynk.setProperty(V1,"color",BLYNK_YELLOW);
} else
{
Blynk.setProperty(V1,"color",BLYNK_RED);
}
delay(100);
Blynk.virtualWrite(V1,MMeasure.Percent[0]); } else
{
Blynk.setProperty(V1,"color",BLYNK_BLUE); }
break;
}
case 1:
{
if ((MMeasure.DataValid[1]) & (Calibrated))
{
if ( MMeasure.Percent[1] > SysConfig.StatusBorderPercentValues[1][1])
{
Blynk.setProperty(V2,"color",BLYNK_GREEN);
} else if ( MMeasure.Percent[1] > SysConfig.StatusBorderPercentValues[1][0]) {
Blynk.setProperty(V2,"color",BLYNK_YELLOW);
} else
{

Blynk.setProperty(V2,"color",BLYNK_RED); }
delay(100);
Blynk.virtualWrite(V2,MMeasure.Percent[1]); } else
{
Blynk.setProperty(V3,"color",BLYNK_BLUE); }
break;
}
case 2:
{
if ((MMeasure.DataValid[2]) & (Calibrated))
{
if ( MMeasure.Percent[2] > SysConfig.StatusBorderPercentValues[2][1])
{
Blynk.setProperty(V3,"color",BLYNK_GREEN);
} else if ( MMeasure.Percent[2] > SysConfig.StatusBorderPercentValues[2][0]) {
Blynk.setProperty(V3,"color",BLYNK_YELLOW);
} else
{
Blynk.setProperty(V3,"color",BLYNK_RED);
}
delay(100);
Blynk.virtualWrite(V3,MMeasure.Percent[2]); } else
{
Blynk.setProperty(V3,"color",BLYNK_BLUE); }
break;
}
case 3:
{
if ((MMeasure.DataValid[3]) & (Calibrated))
{
if ( MMeasure.Percent[3] > SysConfig.StatusBorderPercentValues[3][1])
{
Blynk.setProperty(V4,"color",BLYNK_GREEN);
} else if ( MMeasure.Percent[3] > SysConfig.StatusBorderPercentValues[3][0]) {
Blynk.setProperty(V4,"color",BLYNK_YELLOW);
} else
{
Blynk.setProperty(V4,"color",BLYNK_RED);
}
delay(100);
Blynk.virtualWrite(V4,MMeasure.Percent[3]); } else
{
Blynk.setProperty(V4,"color",BLYNK_BLUE); }

break;
}
case 4:
{
if ((MMeasure.DataValid[4]) & (Calibrated))
{
if ( MMeasure.Percent[4] > SysConfig.StatusBorderPercentValues[4][1])
{
Blynk.setProperty(V5,"color",BLYNK_GREEN);
} else if ( MMeasure.Percent[4] > SysConfig.StatusBorderPercentValues[4][0]) {
Blynk.setProperty(V5,"color",BLYNK_YELLOW);
} else
{
Blynk.setProperty(V5,"color",BLYNK_RED);
}
delay(100);
Blynk.virtualWrite(V5,MMeasure.Percent[4]); } else
{
Blynk.setProperty(V5,"color",BLYNK_BLUE); }
break;
}
case 5:
{
if ((MMeasure.DataValid[5]) & (Calibrated))
{
if ( MMeasure.Percent[5] > SysConfig.StatusBorderPercentValues[5][1])
{
Blynk.setProperty(V6,"color",BLYNK_GREEN);
} else if ( MMeasure.Percent[5] > SysConfig.StatusBorderPercentValues[5][0]) {
Blynk.setProperty(V6,"color",BLYNK_YELLOW);
} else
{
Blynk.setProperty(V6,"color",BLYNK_RED);
}
delay(100);
Blynk.virtualWrite(V6,MMeasure.Percent[5]); } else
{
Blynk.setProperty(V6,"color",BLYNK_BLUE); }
break;
}
case 6:
{
if (DHTMeasure.DataValid)
{
if | (DHTMeasure.Humidity | < | 40) | // | https://www.pflanzenfreunde.com/luftfeuchtigkeit.htm | und
https://www.brune.info/magazin/richtige-luftfeuchtigkeit-fuer-pflanzen/

{
Blynk.setProperty(V7,"color",BLYNK_RED);
} else if (DHTMeasure.Humidity < 60)
{
Blynk.setProperty(V7,"color",BLYNK_YELLOW); } else if (DHTMeasure.Humidity < 85)
{
Blynk.setProperty(V7,"color",BLYNK_GREEN); } else
{
Blynk.setProperty(V7,"color",BLYNK_YELLOW); }
Blynk.virtualWrite(V7,DHTMeasure.Humidity);
}
break;
}
case 7:
{
if (DHTMeasure.DataValid)
{
if (DHTMeasure.Temperature > 43) // https://www.spektrum.de/lexikon/biologie-kompakt/hitzeresistenz/5543 {
Blynk.setProperty(V8,"color",BLYNK_RED);
} else if (DHTMeasure.Temperature < 11) // https://de.wikipedia.org/wiki/K%C3%A4ltestress_bei_Pflanzen {
Blynk.setProperty(V8,"color",BLYNK_RED);
} else
{
Blynk.setProperty(V8,"color",BLYNK_WHITE); }
Blynk.virtualWrite(V8,DHTMeasure.Temperature); }
break;
}
case 8:
{
if (BHMeasure.DataValid)
{
if (BHMeasure.Lux < 500) // https://www.zimmerpflanzenlexikon.info/artikel/lichtbedarf-von-pflanzen {
Blynk.setProperty(V9,"color",BLYNK_RED);
} else if (BHMeasure.Lux < 1000)
{
Blynk.setProperty(V9,"color",BLYNK_GREEN); } else if (BHMeasure.Lux < 1500)
{
Blynk.setProperty(V9,"color",BLYNK_WHITE); } else
{
Blynk.setProperty(V9,"color",BLYNK_YELLOW); }
Blynk.virtualWrite(V9,BHMeasure.Lux);

}
break;
}
} // End Switch
}

void Get_Moisture_DatainPercent()
{
byte CalibDataOffset = 0;
for (byte i = 0;i < AttachedMoistureSensors;i++)
{
CalibDataOffset = i *2;
int RawMoistureValue = ReadMoistureSensor_Raw_Val(i);
if ((SysConfig.Data[CalibDataOffset] == 0) || (SysConfig.Data[CalibDataOffset+1] == 0)) // MinADC Value maxADC ADC Value {
MMeasure.Percent[i] = RawMoistureValue;
MMeasure.DataValid[i] = false;
} else
{
RawMoistureValue= SysConfig.Data[CalibDataOffset+1] - RawMoistureValue; RawMoistureValue=SysConfig.Data[CalibDataOffset] + RawMoistureValue;
MMeasure.Percent[i] = map(RawMoistureValue,SysConfig.Data[CalibDataOffset],SysConfig.Data[CalibDataOffset+1], 0, 100);
if ((MMeasure.Percent[i] > 100 ) | (MMeasure.Percent[i] < 0 ))
{
MMeasure.Percent[i] = RawMoistureValue; MMeasure.DataValid[i] = false;
} else { MMeasure.DataValid[i] = true; } }
}
return ;
}

void Run_MoistureSensors (bool Init) // HauptFunktion zum Betrieb der Bodenfeuchtesensoren {
byte MinSensValue = 100;
if ((millis() - Moisure_ServiceCall_Handler >= MoisureSens_Poll_MinInterval * 1000) | (Init))
{
Moisure_ServiceCall_Handler = millis();
if (Init)
{
for (int i = 0;i < MaxSensors;i++)
{
int MSensorRawValue = ReadMoistureSensor_Raw_Val(i); if ( MSensorRawValue > MinSensorValue)
{
AttachedMoistureSensors++;
} else {break;}
}
if (AttachedMoistureSensors < 1) {
#ifdef DEBUG

Serial.println(F("Keine Bodenfeuchtigkeitssensoren erkannt. System angehalten.")); #endif
SetLedConfig(255,0,255);
digitalWrite(LED_Rot,HIGH); // System angehalten Led Anzeige: lila digitalWrite(LED_Blau,HIGH);
digitalWrite(LED_Gruen,LOW);
delay(1200000);
esp_deep_sleep_start();
while(1) {}
}
for (int i = 0;i < AttachedMoistureSensors;i++)
{
if (i == 0) { Blynk.setProperty(V1,"label",SysConfig.SensorName[0]); } if (i == 1) { Blynk.setProperty(V2,"label",SysConfig.SensorName[1]); } if (i == 2) { Blynk.setProperty(V3,"label",SysConfig.SensorName[2]); } if (i == 3) { Blynk.setProperty(V4,"label",SysConfig.SensorName[3]); } if (i == 4) { Blynk.setProperty(V5,"label",SysConfig.SensorName[4]); } if (i == 5) { Blynk.setProperty(V6,"label",SysConfig.SensorName[5]); } }
for (int i = AttachedMoistureSensors;i < MaxSensors;i++)
{
if (i == 0) { Blynk.setProperty(V1,"label","Deaktiviert"); Blynk.setProperty(V1,"color",BLYNK_BLACK); } if (i == 1) { Blynk.setProperty(V2,"label","Deaktiviert"); Blynk.setProperty(V2,"color",BLYNK_BLACK); } if (i == 2) { Blynk.setProperty(V3,"label","Deaktiviert"); Blynk.setProperty(V3,"color",BLYNK_BLACK); } if (i == 3) { Blynk.setProperty(V4,"label","Deaktiviert"); Blynk.setProperty(V4,"color",BLYNK_BLACK); } if (i == 4) { Blynk.setProperty(V5,"label","Deaktiviert"); Blynk.setProperty(V5,"color",BLYNK_BLACK); } if (i == 5) { Blynk.setProperty(V6,"label","Deaktiviert"); Blynk.setProperty(V6,"color",BLYNK_BLACK); } }
}
Get_Moisture_DatainPercent();
for (int i = 0;i < AttachedMoistureSensors;i++) {
if (MMeasure.DataValid[i])
{
if (MMeasure.Percent[i] != MMeasure.Old_Percent[i])
{
MMeasure.Old_Percent[i] = MMeasure.Percent[i];
if (MMeasure.Percent[i] < MinSensValue ) { MinSensValue = MMeasure.Percent[i]; }; #ifdef DEBUG
Serial.print(F("Feuchtigkeitswert Sensor "));
Serial.print(i);
Serial.print(F(" in Prozent :")); Serial.print(MMeasure.Percent[i]);
Serial.println(F(" %"));
#endif

Update_Blynk_APP(i,Sens_Calib); // Aktualisiere Handywerte }
} else
{
Update_Blynk_APP(i,Sens_NOTCalib); // Aktualisiere Handywerte Serial.print(F("Sensor "));
Serial.print(i);

Serial.print(F(" nicht kalibiert. Bitte kalibrieren. Rohdatenwert:")); Serial.println(MMeasure.Percent[i]);
}
}
Update_Local_Display(); // Aktualisiere lokales Pflanzenwächter Display (Led) }

}

// Main Loop
void loop()
{
Run_MoistureSensors(RunTime);
if (DHTMeasure.SensorEnabled) {Run_DHTSensor(RunTime); } if (BHMeasure.SensorEnabled) {Run_BH1750Sensor(RunTime); } Blynk.run();
}

## In dem Code müssen vor dem ersten Hochladen müssen jedoch noch folgende Codezeilen an die jeweiligen eigenen Bedürfnisse angepasst werden:

int Data[MaxSensors*2] = {0,0,0,0,0,0,0,0,0,0,0,0,};

Werte bitte gemäß Beschreibung in Teil 1 der Reihe anpassen.

## #define MoisureSens_Poll_MinInterval 3600

## Intervall zwischen zwei Bodenfeuchtemessungen in Sekunden. Der Wert hat darauf Einfluss, wie oft die Handydaten der Bodenfeuchtesensoren aktualisiert werden, und

damit auch, welches Datenvolumen für die Übertragung pro Zeit anfällt. Je höher,

## desto größeres Intervall. Bitte auf einen Wert setzen, der zu dem eigenen

Datenvolumen bzw. Budget passt.

## [Beispiel: 3600 s =1 Stunde]

## #define DHT_Poll_MinInterval 2700

Intervall zwischen zwei Temperatur/Luftfeuchtemessungen in Sekunden. Der Wert hat darauf Einfluss, wie oft die Handydaten der Temperatur/Luftfeuchtemessungen aktualisiert werden, und damit auch, welches Datenvolumen für die Übertragung pro Zeit anfällt. Je höher, desto größeres Intervall. Bitte auf einen Wert setzen, der zu dem

eigenen Datenvolumen bzw. Budget passt.

## [Beispiel: 2700 s = 45 Minuten Datenübertragungsintervall]

## #define BH_Poll_MinInterval 1800

Intervall zwischen zwei Beleuchtungsstärkenmessungen in Sekunden. Der Wert hat darauf Einfluss, wie oft die Handydaten der Beleuchtungsstärkenmessungen aktualisiert werden, und damit auch, welches Datenvolumen für die Übertragung pro Zeit anfällt. Je höher, desto größeres Intervall. Bitte auf einen Wert setzen, der zu dem eigenen Datenvolumen bzw. Budget passt. [ [Beispiel: 1800 s = 30 Minuten Datenübertragungsintervall]

char auth[] = "xxxxxxxxxxxxxxxxxxxxxxxxxxxxxxxx";
char ssid[] = "Deine_WLAN_SSID";
char pass[] = "Dein _WLAN _Passwort!";

Werte bitte gemäß Beschreibung in Teil 2 der Reihe anpassen.

## Es können folgende Parameter/Codezeilen, an die jeweiligen Bedürfnisse angepasst werden:

## String SensorName[MaxSensors] = {"Pflanze 1","Pflanze 2","Pflanze 3","Pflanze

4","Pflanze 5","Pflanze 6"};

Sensornamen, der in der APP als Überschrift angezeigt wird.

byte StatusBorderPercentValues[MaxSensors*2][2]= { {10,50}, …..

Zweidimensionales Array für Prozentgrenzwerte (Ampel) jeweils einzeln pro Feuchtesensor (1 -6). Hat Einfluss auf die „Ampel“ Anzeige und die Anzeige der Werte in der APP. Erster Wer (10) gibt die Übergangsgrenze zwischen Status „rot“ und Status „gelb“ an. Zweiter Wert gibt die Übergangsgrenze zwischen Status „gelb“ und Status

„grün“ an. Beispiel: ab 51 % Bodenfeuchte „grün“ ab 9% Bodenfeuchte „rot“.

## #define DEBUG

## Wenn Definition „DEBUG“ vorhanden werden Laufzeitmeldungen auf der seriellen Schnittstelle ausgegeben. Für den produktiven Einsatz kanne die Definition „DEBUG“

gelöscht werden, um unnötige Ressourcenverwendung zu vermeinden..

## Kommen wir nun erneut, wie in den anderen Teilen, zu der Anpassung unserer Handy APP. In dieser müssen wir nun wieder ein neues „H-Level“ Element erzeugen und dieses wie folgend beschriebene Einrichten Wir fügen zur Anzeige der aktuellen Bodenfeuchte das „Level H“ 1-mal hinzu

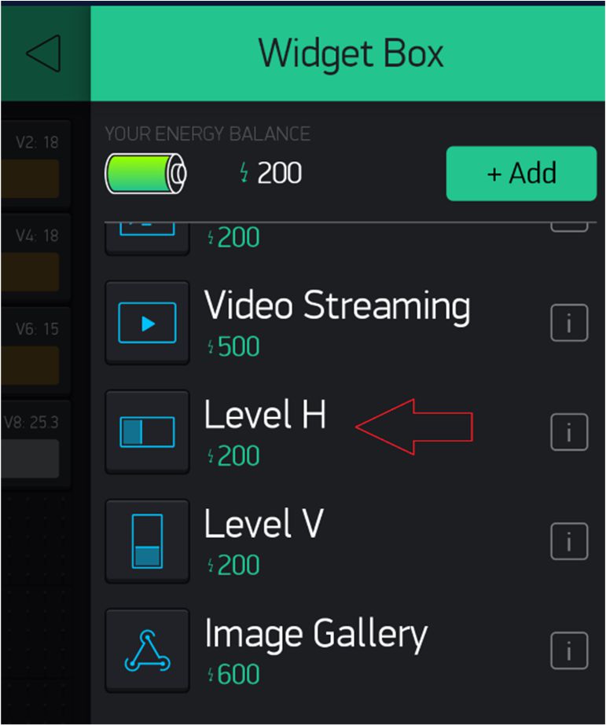
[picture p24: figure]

## Und konfigurieren das neue Element wie folgt:


## - Farbe: Rot - Input Pin: V9 (virtuell) - Minimum Wert: 0 - Maximum Wert: 1400 (oder 1500)

## Die wichtigste Anpassung ist hierbei auch wieder die Input Variable. Diese muss fhier auf „V9“ eingestellt werden Wir definieren wir als Reading Rate abermals „Push“


## Das Endergebnis, bei Aktivierung des Projekts sollte nun ungefähr wie folgt aussehen:


Herzlichen Glückwunsch! Du hast deinen Pflanzenwächter erfolgreich konfiguriert.

## Bitte beachte folgendes:

## Wir haben jetzt auf unserem DashBoard 9 „H-Level“ Anzeigeelemente. Jedes „H-

Level“ Element kostet uns 200 Energie. Dies macht 9*200 = 1800 Energiepunkte.

Ein Hinzufügen von weiteren Elementen, die teurer als 200 Energiepunkte sind, ist ab diesem Punkt nur noch über kostenpflichtige IN-APP Käufe möglich. Die weiteren Beispiele und Screenshots mit Diagrammen sind demnach kostenpflichtig! Zur generellen Funktion des Pflanzenwächters sind diese keinesfalls notwendig! Auch kann nicht garantiert werden, dass zukünftig die APP oder die gekauften Energiepunkte bei zukünftigen Folgereihen noch verwendet oder werden. Bitte

entscheide daher eigenverantwortlich ob du Geld hierin investieren möchtest.

Auch wenn die App in jedem Fall auch OHNE weitere Investition voll Funktionsfähig und ein bereits ein echter Hingucker ist, möchte ich euch die bereits möglichen kostenpflichtigen Erweiterungen nicht vorenthalten. Dazu ist keine Änderung des ESP Codes notwendig. Alle Screenshots sind alleine über die Blynk APP unabhängig von

der Firmware so konfigurierbar.

## Machbarkeitsbeispiel: Temperaturverlauf (zusammen in einem Chart) :


## Machbarkeitsbeispiel: Temperaturverlauf (getrennt in zwei Charts)

## Machbarkeitsbeispiel Beleuchtungsstärkenverlauf


## Weitere Informationen über die Blynk APP und deren Verwendung in Controllern findest du unter:

## - Blynk Einführung -> https://www.blynk.cc/getting-started - Dokumentation -> http://docs.blynk.cc/ - Sketch Generator -> https://examples.blynk.cc/

- Aktuellste | Blynk | Bibliothek | -> | https://github.com/blynkkk/blynk-

## library/releases/download/v0.6.1/Blynk_Release_v0.6.1.zip

- Aktuellster | Blynk | server | -> | https://github.com/blynkkk/blynk-

## server/releases/download/v0.41.5/server-0.41.5.jar - Blynk Startseite -> https://www.blynk.cc

Bitte beachtet, dass dieses Projekt für Hydrokulturpflanzen oder Luftwurzlerpflanzen nicht geeignet ist. Pflanzen haben unterschiedliche Anforderungen an Ihre Umwelt. Da die individuellen Anforderungen der Pflanzen unser Pflanzenwächter nicht kennen kann, liegt die Interpretation der Wertedarstellungen des Pflanzenwächters ausschließlich in der Hand des Anwenders

## Der Pflanzenwächter ist kein Ersatz für eine verantwortungsvolle Pflege der Pflanzen!

Ihr könnt dieses Projekt sowie andere Projekte von mir auch auf meiner Git-Hub Seite, finden.

Viel Spaß beim Nachbauen.

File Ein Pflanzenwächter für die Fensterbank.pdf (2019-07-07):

## Ein Pflanzenwächter für die Fensterbank

Heute möchte ich euch ein neues interessantes mehrteiliges Projekt mit dem vielseitigen und leistungsfähigen ESP 32 vorstellen. Wie bauen uns einen Pflanzenwächter für unsere heimischen Plantae. Dieser soll während wir unsere Aufmerksamkeit unseren spannenden Elektronikprojekten widmen, den Wassergehalt der Erde überwachen und uns darüber informieren, wenn die Bodenfeuchte sinkt. Dazu hat unser Pflanzenwächter eine LED-Ampel, die bei feuchter Erde grün leuchtet und bei trockener Erde über gelb rot wird. Bevor wir jedoch mit dem Projekt beginnen, müssen wir uns jedoch noch, vor dem eigentlichen Start des Projektes einige Gedanken machen. Dies betrifft vorallendigen den Einsatz des Pflanzenwächters. Da unser Pflanzenwächter die Feuchtigkeit der Erde über eine kapazitive Nahfeldmessung bestimmt, ist es notwendig, dass die Feuchtigkeit in unmittelbarer Nähe des Sensors gespeichert wird. Während i.d.R. normale (Blumen-)Pflanzenerde aus dem Baumarkt oder dem Supermarkt diese Bedingung erfüllt, ist dies bei u.a. Hydrokultursubstraten oder Orchideensubstrat nicht der Fall! Daher:
Dieses Projekt ist für Hydrokulturpflanzen oder Luftwurzlerpflanzen (wie z.B. Orchideen) nicht geeignet!

Außerdem haben Pflanzen ganz unterschiedliche Anforderungen an Ihre Bewässerung. Während mache Pflanzen eine dauerhafte Grundfeuchte (meistens keine Staunässe) bevorzugen, sind mache dagegen eher trockenliebend und möchten nur selten gegossen werden. Da die individuellen Anforderungen der Pflanze unser Pflanzenwächter nicht kennen kann, liegt die Interpretation der nötigen Aktionen (gießen oder nicht gießen) auf die (Ampel-) Anzeige des Pflanzenwächters ausschließlich in der Hand des botanisch kundigen Anwenders .

Der Pflanzenwächter ist daher kein Ersatz für eine verantwortungsvolle- und pflanzengerechte Pflege deiner Pflanzen!

Im weiteren Verlaufe des Projektes und mit größer werden dem Umfang werden wir weitere Sensoren anbinden und natürlich auch Komfortfunktionen hinzufügen. Lasst euch überraschen!
Aber fangen wir mit der Basis an. Schauen wir uns die Bauteile an, die wir für unseren Pflanzenwächter für den Anfang brauchen:
- 1 x LED Farbe Grün (560nm); 5 mm
- 1x LED Farbe Gelb (605nm); 5 mm
- 1x LED Farbe Rot (633nm); 5 mm
- 6x130kΩ Wiederstand Toleranz ±1%;
- 6x 47kΩ Wiederstand Toleranz ±1
- 3x 150Ω Wiederstand Toleranz ±1%;
- 1x Kapazitiver Feuchtesensor
- 1x ESP32-38Pin Variante Generic; Typ NodeMCU-32S; Beinchen 38;
- 1x YwRobot Breadboard Spannungsversorgung

Wir verdrahten die Komponenten wie folgt:


Die 150 Ohm Widerstände werden als Vorwiederstände für die LEDs genutzt. Der 130 KOhm bildet zusammen mit dem 47 KOhm Wiederstand ein Spannungsteiler für den Analogausgang des Feuchtigkeitssensors.
Wir laden folgenden Code auf unseren ESP 32 hoch:
#include <driver/adc.h>

// Portedefinierung Led's
#define LED_Rot | 5 | // Rote LED

#define LED_Gelb 14 // Gelbe LED #define LED_Gruen 15 // Gruene LED

// LED PWM Einstellungen
#define PWMfreq 5000 // 5 Khz basisfrequenz #define PWMledChannelA 0

#define PWMledChannelB 1

#define PWMledChannelC 2

#define PWMresolution 8 // 8 Bit Resolution

#define ADCAttenuation ADC_ATTEN_DB_11 //ADC_ATTEN_DB_11 = 0-3,6V Dämpung ADC Einstzellung

#define MaxSensors 1

struct MoistureSensorCalibrationData
{
int Data[MaxSensors*2] = {0,0}; // Calibration Data für Feuchtigkeitssensor. Bitte Projekt Text beachten und Werte ensprechend anpassen
};

struct MoistureSensorData
{
byte Percent[MaxSensors] = {0}; // Feuchtigkeitssensordaten in Prozent };

//Global Variables
MoistureSensorCalibrationData MCalib;
MoistureSensorData MMeasure;
byte AttachedMoistureSensors; // Detected Active Moisture Sensors (Count)

void setup() {
// initialize serial communication at 9600 bits per second: pinMode(LED_Rot,OUTPUT);
pinMode(LED_Gelb,OUTPUT);
pinMode(LED_Gruen,OUTPUT); Serial.begin(115200);
ledcSetup(PWMledChannelA, PWMfreq, PWMresolution); ledcSetup(PWMledChannelB, PWMfreq, PWMresolution); ledcSetup(PWMledChannelC, PWMfreq, PWMresolution); ledcAttachPin(LED_Rot, PWMledChannelA); // attach the channel to the GPIO to be controlled
ledcAttachPin(LED_Gelb, PWMledChannelB);

ledcAttachPin(LED_Gruen, PWMledChannelC); SetLedConfig(20,20,20);
AttachedMoistureSensors = DetectMoistureSensors(); Serial.println(F("Systemkonfiguration:")); Serial.print(AttachedMoistureSensors); Serial.println(F(" Bodenfeuchtigkeitsensor(en)"));
}

byte DetectMoistureSensors ()
{
#define MinSensorValue 100 byte Detected = 0;

for (int i = 0;i < MaxSensors;i++)
{
int MSensorRawValue = ReadMoistureSensorVal(i);
if ( MSensorRawValue > MinSensorValue) { Detected++; } else {break;} }
if (Detected < 1)
{
Serial.println(F("Keine Bodenfeuchtigkeitssesoren erkannt. System angehalten."));
esp_deep_sleep_start();
while(1) {}
}
return Detected;
}

bool SetLedConfig(byte Red,byte yellow,byte green) {
ledcWrite(PWMledChannelA, Red); // Rote LED ledcWrite(PWMledChannelB, yellow); // Gelbe LED ledcWrite(PWMledChannelC, green); // Gruene LED return true;
}

int ReadMoistureSensorVal(byte Sensor)
{
int ReturnValue,i;
long sum = 0;
#define NUM_READS 6

adc1_config_width(ADC_WIDTH_BIT_12); //Range 0-4095 switch (Sensor)
{
case 0:
{
adc1_config_channel_atten(ADC1_CHANNEL_0,ADCAttenuation); for (i = 0; i < NUM_READS; i++){ // Averaging algorithm
sum += adc1_get_raw( ADC1_CHANNEL_0 ); //Read analog
}
ReturnValue = sum / NUM_READS;
break;

}
}
return ReturnValue;
}

bool GetMoistureData()
{
bool ReadisValid = true;
for (int i = 0;i < AttachedMoistureSensors;i++)
{
if ((MCalib.Data[i] == 0) || (MCalib.Data[i+1] == 0)) // MinADC Value maxADC ADC Value
{
ReadisValid = false;
return ReadisValid;
}
int RawMoistureValue= ReadMoistureSensorVal(i);
RawMoistureValue= MCalib.Data[i+1] - RawMoistureValue; RawMoistureValue=MCalib.Data[i] + RawMoistureValue;
MMeasure.Percent[i] = map(RawMoistureValue,MCalib.Data[i],MCalib.Data[i+1], 0, 100);
if (MMeasure.Percent[i] > 100 ) { ReadisValid = false; }
}
return ReadisValid;
}

// Main Loop
void loop()
{
if (GetMoistureData())
{
Serial.print(F("Feuchtigkeitswert Sensor 1 in Prozent :")); Serial.print(MMeasure.Percent[0]);
Serial.println(F(" %"));
if (MMeasure.Percent[0] > 50)
{ SetLedConfig(0,0,20); }
else if (MMeasure.Percent[0] > 10) { SetLedConfig(0,255,0); }
else
{ SetLedConfig(255,0,0); }
}
else
{
Serial.print(F("Bodenfeuchtigkeitssensor nicht kalibiert.Bitte kalibieren. RohDaten des Sensors 1:"));
Serial.println(ReadMoistureSensorVal(0));
SetLedConfig(20,20,20);
}
delay(1000); // delay between reads for stability }

Als letzten Schritt müssen wir nun die Kalibrierung unseres Feuchtigkeitssensors durchführen. Die Kalibrierung des Sensors legt fest, was als trockene Erde (Wassergehalt 0%) und was nasse Erde (Wassergehalt 100%) erkannt wird. Dazu strecken wir den Feuchtigkeitssensor als erstes in absolut trockene Erde und lassen uns die Sensor- Rohdaten auf der seriellen Schnittstelle ausgeben:
Wert 1: (Trocken)


Wir notieren uns den Wert (2276) und bewässern nun die Erde solange, bis sie komplett! durchnässt ist und kein Wasser mehr ausnehmen kann. Wir notieren uns den Wert 2: (Nasse Erde) (1648)


Wir addieren zu dem ersten Wert 2276, 10 dazu und ziehen von 1648, 10 ab. Es ergeben sich daraus die Werte 2286 und 1638
Wir tragen die Werte in unseren Code ein:
struct MoistureSensorCalibrationData
{
int Data[MaxSensors*2] = {1638,2286}; };
Und laden den Code erneut hoch.

Wir erhalten folgende Ausgabe:


Gleichzeitig zeigt unsere Led „Ampel“ grün an. Dabei bedeuten die Farben: Grün: Feuchtigkeit hoch.
Gelb: Feuchtigkeit mittelmäßig.
Rot: Trocken.
Viel Spaß beim Nachbauen und bis zum nächsten Teil der Serie.

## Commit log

2019-06-25 Teil 1 der Planzenwächterreihe
2019-07-02 Fritzing Schaltplan Pfläanzenwächter Teil 1
    Fritzing Schaltplan Pfläanzenwächter Teil 1
    [Pflanzenwächter_Schematic.fzz]
2019-07-02 Fritzing Schaltplan Pflanzenwächter Teil 3
    Fritzing Schaltplan Pflanzenwächter Teil 3
    [Pflanzenwächter_Schematic_Teil3.fzz]
2019-07-02 Fritzing Schaltplan Pflanzenwächter Teil 4
    Fritzing Schaltplan Pflanzenwächter Teil 4
    [Pflanzenwächter_Schematic_Teil4.fzz]
2019-07-02 Arduino Quellcode Pflanzenwächter Teil 2
    Arduino Quellcode Pflanzenwächter Teil 2
2019-07-02 Arduino Quellcode Pflanzenwächter Teil 3
    Arduino Quellcode Pflanzenwächter Teil 3
2019-07-07 Arduino Quellcode Pflanzenwächter Teil 4
2019-07-07 Arduino Quellcode Pflanzenwächter Teil 5
2019-07-07 Fritzing Schaltplan Pflanzenwächter Teil 5
    [Pflanzenwächter_Schematic_Teil5.fzz]
